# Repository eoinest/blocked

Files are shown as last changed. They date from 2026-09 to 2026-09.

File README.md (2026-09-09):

# blocked

A physical button for a very specific code review style.

Open a pull request in Google Chrome. Press the key. GitHub gets a
**Request changes** review that says:

> blocked

An ESP32-S2 Mini, one mechanical switch, a printed case, and a small native Mac
menu bar app. No browser extension, cloud service, or GitHub token on the board.

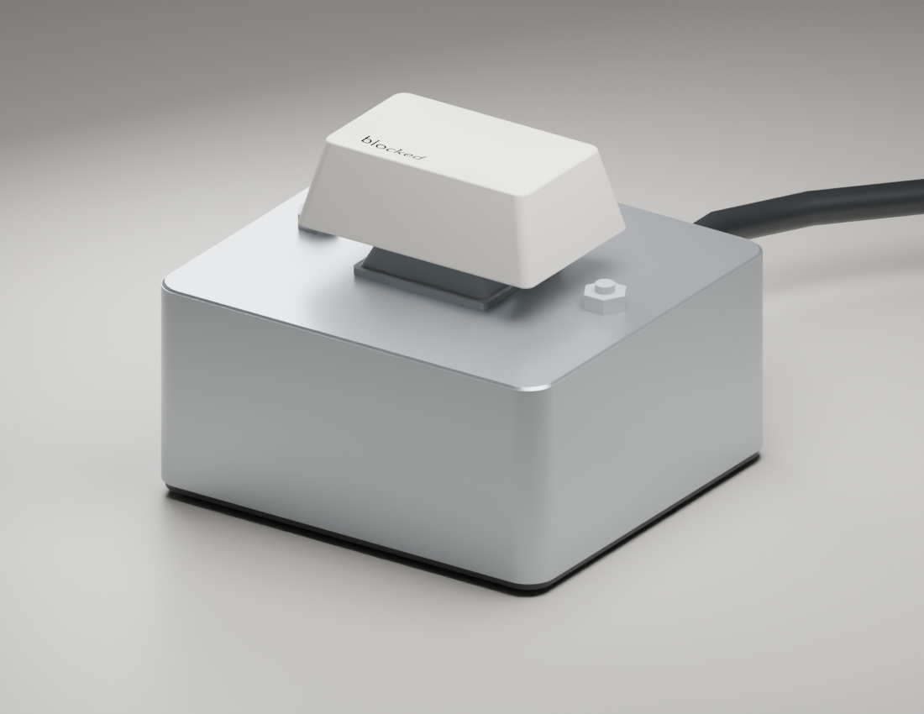
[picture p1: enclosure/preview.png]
Blender enclosure concept: blocked key


**Status:** initial prototype. Source, firmware, and printable enclosure files
are provided; physical assembly and an actual button-to-review test are still
required. The companion now has first-run setup, bundled GitHub support,
remembered enable/pause state and optional launch at login. A signed/notarized
release and clean-Mac acceptance testing are still outstanding.

Verified locally: ESP32-S2 firmware compile, button-state regression checks,
43 offline companion tests, a universal Intel/Apple Silicon Mac app build, and mesh
checks for the printable parts. [CI configuration](ci/) is supplied as
an inactive template because the initial publishing credentials lacked workflow
permission.

## The build

| Part | Plan |
| --- | --- |
| Controller | Your existing LOLIN-style ESP32-S2 Mini, powered by USB-C |
| Key | Gateron Baby Kangaroo 2.0 tactile switch with a custom 1.5u `blocked` keycap |
| Wiring | Two soldered wires: GPIO4 → switch → GND; internal pull-up |
| Case | 46 × 42 × 22 mm body; two M1.6 screws through dedicated PCB mounting holes; two M2 case screws; all screws enter from below with exposed nuts above; four PCB supports, rear USB-C cutout, recessed feet |
| Mac | Native Swift menu bar app, USB serial, Chrome Automation, existing `gh` credentials |

The board sends a debounced press over USB serial. The Mac app checks that
Google Chrome is frontmost, reads the active tab in its front window, validates
the GitHub PR URL, and runs:

```sh
gh pr review https://github.com/OWNER/REPO/pull/NUMBER --request-changes --body blocked
```

That command really posts a review. Use **Test next press (no review)** for diagnosis.
The review is authored by the account authenticated in **GitHub CLI**, which may
differ from the account signed into Chrome. GitHub's permissions and branch
rules still apply.

## General-purpose command buttons

[Key Command](key-command/README.md) is a separate macOS app for assigning each button a shell command or keyboard shortcut. It uses [separate firmware](firmware/key_command/README.md), supports multiple boards, and runs alongside Blocked. The [three-button print plate](docs/three-button-print.md) includes three enclosures and three blank Tab caps.

## Make one

For soldering and switch checks, open the [standalone USB Button Tester](docs/button-test.md).

For an immediately printable keycap, use the [three Tab shapes and combined
A1 print plate](keycap/printed/README.md), including socket-fit testers.

1. Start with the [condensed shopping list](BOM.md) and [custom keycap order settings](keycap/README.md), then check your board against [the hardware guide](docs/hardware.md).
2. Verify the switch coupon and clip the switch into the lid using the [key mounting guide](docs/key-mounting.md). Solder the two wires, then [build and flash the firmware](firmware/README.md).
3. [Build and install the Mac companion](companion/README.md). Its setup window
   reuses an existing GitHub sign-in or connects through the browser, then requests
   Chrome access. The default app includes its own GitHub helper.
4. Keep the button paused, choose **Test next press (no review)**, then focus a PR
   and press the key. Verify the target and body.
5. Check [component dimensions and remaining measurements](docs/component-accuracy.md), then print the fastener coupons and remaining [enclosure parts](docs/enclosure.md).
   Mount the PCB through its two dedicated holes with M1.6 × 6 mm screws, then
   close the lid with two M2 × 20 mm socket-cap screws. All screws enter from
   below with exposed nuts above; four pads support the board. Check your
   Maierke kit for these new screw lengths.
   Add the keycap and adhesive feet.
6. Enable Blocked once when ready. Its enabled/paused state survives restarts.

The [key mounting guide](docs/key-mounting.md) covers the switch's plate clips,
reinforced lid, centred Tab keycap socket, full travel and service access.

See [the staged bring-up checklist](docs/bring-up.md) for assembly and the
physical acceptance checks. Building the gift needs a USB data cable, a soldering iron,
and a Mac development toolchain. The recipient gets a pre-flashed button and
should only need the installed companion app; see the [experience target](docs/user-experience.md). The board uses no Wi-Fi.

## Customize it

The companion supports request-changes, comment, and approve review actions,
with an editable message. Its default is request-changes + `blocked`. The
enclosure is parametric so you can adjust dimensions and printer tolerances.
The initial supported browser is stable Google Chrome on macOS; the supported
GitHub host is `github.com`.

| Directory | Contents |
| --- | --- |
| [`firmware/`](firmware/) | ESP32-S2 Arduino sketch, pinned build configuration, button-state tests |
| [`companion/`](companion/) | Swift menu bar app, settings, app packaging, automated tests |
| [`enclosure/`](enclosure/) | Editable CAD, printable parts, fit coupon, preview |
| [`docs/`](docs/) | Sourced hardware research, architecture, assembly and validation |

[Architecture and alternatives](docs/architecture.md) explains why USB serial
and macOS automation were chosen. [Contributions](CONTRIBUTING.md) are welcome.

## License

MIT, including the original firmware, companion, documentation, and enclosure
design files. See [LICENSE](LICENSE).

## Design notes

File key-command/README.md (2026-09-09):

# Key Command

A separate macOS app that turns each ESP32-S2 button into a **shell command or keyboard shortcut**. Assign different actions to different buttons; each assignment follows the board's stable chip ID when USB paths change. It has its own app bundle, preferences, firmware identity and source package. The existing Blocked app remains independent.

## Install and use

1. Open `dist/KeyCommand-0.1.0-beta.dmg`, drag **Key Command.app** to Applications, and launch it. This beta is ad-hoc signed, not Apple-notarized; the included Start Here file explains the first-open step.
2. Flash additional boards with [Key Command firmware](../firmware/key_command/README.md). The original Blocked firmware is a different product and is not automatically converted. Wire each normally-open switch between GPIO 4 and GND.
3. Plug in a board using a USB data cable. Give it a name, choose **Shell command** or **Keyboard shortcut**, configure the action and enable it. New boards start disabled.
4. For shortcuts, explicitly grant Key Command Accessibility access. Pressing the physical button sends the shortcut to the app currently in focus. Shell-only use does not require Accessibility.
5. Leave Key Command running in the menu bar. Enable **Open at login** for automatic startup. Normal USB reconnection needs no reset-button presses or repeated configuration.

The recipient needs the app and a pre-flashed button. No GitHub login, Chrome extension, Homebrew or Swift installation is needed to run the app. Commands can of course depend on tools the recipient has chosen to install.

## Shell commands

Commands run with your macOS user's permissions through `/bin/zsh -lc`. Enter a command or script and choose its working directory. Use absolute executable paths when a tool is not on the configured PATH. Shell expansions, pipes and redirections work because this is an intentional command runner.

A harmless first check:

```sh
/usr/bin/say 'Button connected'
```

The app shows completion status and bounded output, provides a timeout and cancellation, and drops repeated presses while that button's action is running. Commands read from `/dev/null` rather than an interactive terminal. Commands requiring a password prompt or a full interactive terminal need a different workflow. Only configure commands you intend to execute; commands and output are local user data, never bundled into the DMG.

## Keyboard shortcuts

Record the shortcut in the app. A physical press sends a balanced key-down/key-up pair with the chosen modifiers to the focused application. The manual shortcut test provides time to switch to the target app. macOS Accessibility approval is requested only when you choose to grant it; the app does not change system permissions itself.

Keyboard layouts, secure text fields and reserved system shortcuts can affect whether a target accepts a synthesized shortcut. Confirm the actual target app's behavior. This mode does not type a shell command into a terminal.

## Connection behavior

- Only USB devices named **Key Command**, using the Espressif development-board VID, are candidates.
- A separate versioned handshake identifies each board by 12 uppercase hexadecimal characters.
- Multiple connected boards have independent assignments and connection state.
- Duplicate, malformed, unhandshaken and buffered burst events do not run actions.
- Reconnection and a pause after sleep start a fresh handshake; held buttons must be released before another action can fire.
- USB identity associates settings with hardware; it is not cryptographic authentication.

## Build and package

Requires macOS 13+ and the Xcode command-line tools. There are no external Swift package dependencies.

```sh
cd key-command
swift test
./scripts/build-app.sh
./scripts/package-release.sh
```

The scripts create a universal **arm64 + x86_64** app and a verified DMG with an Applications shortcut. They do not modify `/Applications` or flash boards. Artifacts are in `key-command/dist/` and excluded from Git.

For a Developer ID signed and notarized release, with your existing signing identity and Keychain notary profile:

```sh
./scripts/package-release.sh \
  --sign 'Developer ID Application: Your Name (TEAMID)' \
  --notarize-profile YOUR_EXISTING_PROFILE
```

No notarization upload occurs unless that option is supplied. Ad-hoc beta signing does not provide Apple notarization or stable Developer ID permission continuity across builds.

## Hardware and printing

The [three-button print plate](../docs/three-button-print.md) contains three copies of the latest enclosure and three blank Tab caps. The socket-hugging USB collar is still conditional on the actual board and seated cable; follow the [USB fit procedure](../docs/usb-fit.md) before committing to the complete print.

The [firmware guide](../firmware/key_command/README.md) covers build, explicit-port upload and protocol diagnostics. Firmware compilation and simulated transport tests do not replace physical tests with the additional boards.

## Platform references

Apple documents [Accessibility trust](https://developer.apple.com/documentation/applicationservices/1459186-axisprocesstrustedwithoptions) and [main-app login registration](https://developer.apple.com/documentation/servicemanagement/smappservice/mainapp). These system controls are separate from per-button action settings.

MIT licensed; see [LICENSE](../LICENSE).

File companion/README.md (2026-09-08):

# Blocked for macOS

For soldering checks, use the separate [USB Button Tester](../docs/button-test.md):
a live pressed/released display and counter with no GitHub actions.

A small native menu bar app connects the USB button to the pull request in the active Google Chrome window. No browser extension or injected JavaScript is needed. The default review is **Request changes**, with the body **blocked**.

## Recipient experience

The gift should arrive **assembled, flashed and tested**. The recipient installs
Blocked from the disk image by dragging it into Applications, opens it once,
and completes its setup window:

1. **GitHub:** the app checks for an existing GitHub CLI sign-in and displays the
   account. If needed, **Connect GitHub** displays a one-time code and opens
   GitHub's browser authorization page. No Terminal, token copying, or Homebrew
   installation is required by the default app build. GitHub calls this the
   **GitHub CLI** authorization because the bundled helper owns the sign-in.
2. **Chrome:** choose **Allow Chrome** and accept macOS's Automation prompt.
   Blocked reads the focused tab URL, not page contents. If permission was
   previously denied, the setup window explains where to change it in Settings.
3. **Enable Blocked:** the window shows the selected action and message. Leave
   **Open Blocked when I log in** checked to keep it available after restarting
   the Mac. macOS may require approval in Login Items.
4. Plug in the pre-flashed button with a USB data cable, open a PR in Chrome,
   and press. No serial-port selection or per-launch arming is needed.

Unplugging and reconnecting starts a fresh USB session automatically. The app
rescans for the button while disconnected, so a changed USB port name is fine.
Leave Blocked running in the menu bar; installing it alone does not start a
process after you explicitly quit it. With **Open at login** enabled, it starts
again when you sign into your Mac. No BOOT or RESET press is needed for normal use.

For the single file to send to a friend, see [packaging and distribution](../docs/distribution.md).

Enabled/paused state survives app restarts. **Pause button** stops submissions
until enabled again. Changing action/message or advanced settings requires
accepting the new configuration once. GitHub sign-in and Chrome's permissions
remain controlled by GitHub and macOS; the app cannot skip those consent screens.
The GitHub account used can differ from the one signed into Chrome.

Success and error feedback appears briefly without activating Blocked or stealing
Chrome's focus. **Last result…** retains the full message. For diagnosis, choose
**Test next press (no review)**: that one physical press detects the PR and shows
its action without launching a review command. For repeated bench tests, keep
Blocked paused and select this option before each test press.

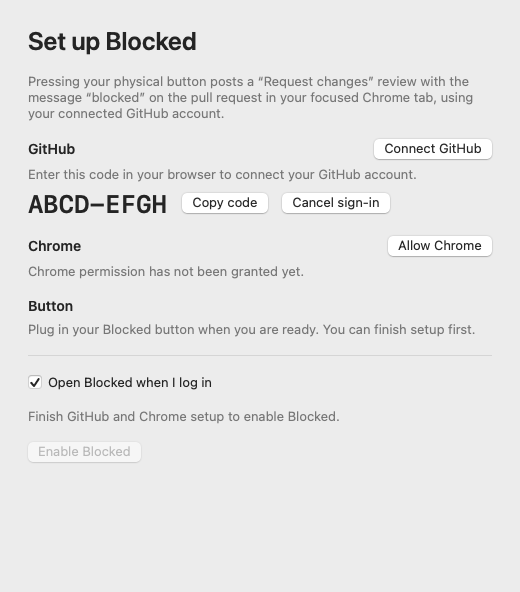
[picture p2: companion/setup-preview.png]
Native setup example with a fictitious device code


## Build and install

Development requires macOS 13+, Xcode/Swift 5.9+ and its selected command line
tools. The recipient does not need Xcode. There are no third-party Swift
packages. The default packaging script includes a pinned GitHub CLI executable
for Intel and Apple Silicon; archive SHA256 checks run before extraction and
on cached builds. Its MIT license ships with the app.

```sh
cd companion
swift test
./scripts/build-app.sh
```

Copy `dist/Blocked.app` to `/Applications`, then open it. The first packaging build
needs internet to download the verified helper archives. Later builds can use
`./scripts/build-app.sh --offline`. `--without-gh` is an explicit developer-only
option that uses an existing GitHub CLI installation; do not distribute that
variant as a self-contained app. See [bundled helper provenance](ThirdPartyNotices/GitHubCLI.md).

The helper reuses GitHub CLI's configuration and credential storage. Existing
Homebrew installations remain a fallback for developer builds. An absolute
helper path and serial port override remain available under Settings for
troubleshooting; neither is part of normal setup. Authentication output is
parsed in memory; device codes are not persisted. Cancel stops the sign-in
process, then rechecks whether credentials were saved before cancellation.

The script signs locally with an ad-hoc signature and stable bundle ID
`io.github.eoinest.blocked`. This is a **source-built prototype, not a notarized
installer**. A frictionless downloadable release still needs Developer ID
signing (`SIGNING_IDENTITY`), notarization and stapling, plus clean-Mac testing.
A rebuilt ad-hoc app may need Automation permission again. No login item is
registered by the build script: only enabling the setup checkbox or choosing
**Open at login** in the running app requests registration.

Chrome must be frontmost when the press is handled. Opening Blocked settings
means Chrome is no longer the target. Conversation, files (`/files` and `/changes`), commits and checks
views are supported; query strings and anchors are ignored when constructing
its canonical PR URL. Other browsers, Enterprise hosts, issues and arbitrary
subpaths remain unsupported. Chrome's “Allow JavaScript from Apple Events”,
Accessibility and Input Monitoring permissions are not required.

## What happens on a press

`USB CDC → identity + sequence check → foreground Chrome + active tab → strict PR URL parser → gh pr review`

The app uses `NSWorkspace.frontmostApplication` and read-only Apple events addressed to that exact process ID to read Chrome's front-window ID, active-tab ID, and URL. Addressing Chrome by bundle ID can select a separate background automation instance, so the reader never falls back to that lookup. It reads twice, requires matching results, and rejects reads taking one second or more. It then launches `gh` with a separate argument array, without a shell. The operation targets the captured PR URL. A tab switch after `gh` starts cannot recall the already-started network request.

There is no press queue. Busy presses, bursts, duplicate sequence numbers, data delayed by a blocked run loop/sleep, and presses inside the two-second debounce window are discarded. A live attempt reserves that PR for ten seconds, including failures. `gh` has a twenty-second timeout and is never retried automatically: a timeout may mean GitHub received the review but its response was lost. Check the PR before trying again. GitHub may reject self-reviews, closed PRs, or reviews the signed-in account cannot submit; those errors are shown as returned by gh.

No PR URL or review body is persisted by Blocked, except the configured message in macOS preferences. The latest result stays in memory. Subprocess output uses a private temporary directory removed on completion. User-supplied custom `gh` paths must point to an executable you trust.

## USB protocol v1

CDC serial, 115200 baud, 8 data bits, no parity, one stop bit, no hardware flow control. The host asserts **both DTR and RTS** because the ESP32 Arduino CDC connection implementation requires both. The firmware's USB product name is `Blocked Key`, using Espressif's vendor ID `0x303a` and the LOLIN S2 Mini's existing product ID `0x80c2`. Automatic discovery filters by vendor and product name; an explicitly configured `/dev/cu.*` port bypasses discovery only.

```text
host → board: HELLO\n
board → host: BLOCKED_KEY 1\n
board → host: PRESS 1\n
board → host: PRESS 2\n
host → board: RESULT DRY_RUN\n
host → board: RESULT OK\n
host → board: RESULT ERROR\n
```

Identity is a version/compatibility check, not cryptographic authentication. Sequence numbers must increase within a connection. A new connection starts a fresh session and flushes input. The host retries HELLO while awaiting identity; repeated identity responses do not reset the host's sequence check. The board requires a debounced release after handshaking before emitting a new press; holding the key while plugging it in cannot submit a review. Result lines are optional feedback and can be ignored by the board.

## Verification

`swift test` runs the offline regression suite and skips the opt-in Chrome integration test.
Coverage includes URL boundaries, exact window/tab identities, application or tab
changes during capture, slow reads, dry run without even looking up gh, busy
presses, per-PR failure cooldowns, and the production press coordinator through a
real local fake-gh subprocess. Runner tests check exact `--request-changes` and
`blocked` arguments, authentication/self-review/permission errors, silent failures,
interruptions, noninteractive execution, timeouts and no automatic retries.
These default tests make no network calls and never submit reviews. Additional
tests cover remembered enable/pause state, setup readiness, browser device-code
parsing, existing-account checks, cancellation, timeout, and stale auth callbacks.

For a real Chrome smoke test, close any sensitive modal dialogs and leave the
desktop idle, then run from `companion`:

```sh
BLOCKED_CHROME_INTEGRATION=1 swift test --filter ChromeIntegrationTests
```

This opens two disposable Chrome windows, switches a tab, checks PR versus issue
URLs, verifies rejection when Finder is foreground, and closes its own windows.
It restores the previously active app. macOS can request Automation permission for
the test runner. The fixture URLs need not resolve to real PRs; this tests URL
detection, not remote PR existence. It never invokes gh or submits a review.
If macOS prevents foreground activation, `BLOCKED_CHROME_INTEGRATION=reader`
tests real Apple-event window/tab responses with an injected foreground identity;
that mode **does not verify actual foreground-app detection**.

The Swift app and packaging can be built without hardware. A fresh recipient Mac
still needs its own first-run and physical unplug/replug checks. A test runner's
Automation permission does not establish that the packaged app has permission.
See the root bring-up instructions.

### Local verification — September 7, 2026

- Physical switch → ESP32 USB → packaged companion → focused Chrome PR → GitHub
  request-changes review with body `blocked` passed on the assembled device.
  The user confirmed success and dismissed the test review afterward.
- Fixed targeting when background Chrome automation processes share the same
  bundle ID as the visible browser; all reads now address the captured PID.
- Changed the per-PR cooldown to ten seconds and verified its boundary tests.
- The development app uses the user's existing GitHub sign-in; distributed
  artifacts contain the app and bundled CLI, not credentials or preferences.

### Local verification — September 5, 2026

- **Passed:** 43 offline tests, including the production press flow through fake gh.
- **Passed:** universal release build, Apple Silicon/Intel architecture check,
  and strict code-signature verification.
- **Unresolved:** the live Chrome smoke test could not establish its disposable
  window as the front window. Full-focus mode also encountered another foreground
  app. Reader-only mode still observed a different Chrome window after attempting
  to raise the fixture, so neither live mode is recorded as passing. The test
  cleaned up its fixture windows. Rerun interactively on an idle desktop.
- **Not performed:** any real GitHub review submission, packaged-app permission
  onboarding, or physical USB-button test.

Testing also fixed empty error messages from silent gh failures, added an explicit
ambiguous-result message for interrupted gh processes, and corrected the `lipo`
argument order in the optional CI template. That template remains inactive until
installed under `.github/workflows` with appropriate GitHub permissions.

## Primary references

- [Apple: frontmostApplication](https://developer.apple.com/documentation/appkit/nsworkspace/frontmostapplication)
- [Chromium: AppleScript support](https://www.chromium.org/developers/design-documents/applescript/) — installed Chrome's `Contents/Resources/scripting.sdef` additionally declares `active tab`, `URL`, and window/tab IDs.
- [Apple: NSAppleEventsUsageDescription](https://developer.apple.com/documentation/bundleresources/information-property-list/nsappleeventsusagedescription)
- [Apple: Apple Events entitlement](https://developer.apple.com/documentation/bundleresources/entitlements/com.apple.security.automation.apple-events)
- [GitHub CLI: gh pr review](https://cli.github.com/manual/gh_pr_review)
- [ESP32 Arduino: LOLIN board definitions](https://github.com/espressif/arduino-esp32/blob/3.3.1/boards.txt) and [USB CDC implementation](https://github.com/espressif/arduino-esp32/blob/3.3.1/cores/esp32/USBCDC.cpp)

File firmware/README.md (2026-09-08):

# ESP32-S2 firmware

The sketch turns one normally-open mechanical switch into a USB CDC serial device. It does not type keys, join Wi-Fi, or store GitHub credentials. The Mac app decides what a press does.

## Build

Install [Arduino CLI](https://arduino.github.io/arduino-cli/latest/installation/). Development uses CLI **1.3.1** and Arduino ESP32 **3.3.1**. The checked-in `sketch.yaml` pins the board core and USB settings; the first profile build downloads its dependencies.

From the repository root:

```sh
ARDUINO_NETWORK_CONNECTION_TIMEOUT=600s arduino-cli compile --profile s2-mini firmware/blocked_key
```

The first build downloads large tool archives for the ESP32 core; the longer network timeout avoids Arduino CLI's default 60-second download limit. [Arduino CLI configuration](https://arduino.github.io/arduino-cli/1.3/configuration/)

The profile uses `esp32:esp32:lolin_s2_mini`, **USB CDC On Boot = Disabled**, **USB MSC On Boot = Disabled**, and **USB DFU On Boot = Disabled**. CDC is disabled *on boot* because the sketch creates its own `USBCDC` interface with product name **Blocked Key** before calling `USB.begin()`; the running firmware still exposes USB serial. Do not enable the boot CDC instance as well.

For an entirely project-local tool cache (optional):

```sh
export ARDUINO_DIRECTORIES_DATA="$PWD/.arduino/data"
export ARDUINO_DIRECTORIES_DOWNLOADS="$PWD/.arduino/downloads"
export ARDUINO_DIRECTORIES_USER="$PWD/.arduino/user"
export ARDUINO_BUILD_CACHE_PATH="$PWD/.arduino/build-cache"
ARDUINO_NETWORK_CONNECTION_TIMEOUT=600s arduino-cli compile --profile s2-mini firmware/blocked_key
```

## Flash

Close the companion app, Button Tester and serial monitors first. Use a **data-capable** USB-C cable. Flashing replaces any existing MicroPython or other program on this board.

1. Hold the board's **0 / BOOT** button.
2. Tap and release **RST / RESET**, then release **0 / BOOT**. This selects the ROM USB downloader. Alternatively hold BOOT while plugging in USB, then release it.
3. Run `arduino-cli board list` and copy this board's `/dev/cu.usbmodem...` path.
4. Upload, replacing the example port:

```sh
arduino-cli upload --profile s2-mini --port /dev/cu.usbmodemYOUR_BOARD firmware/blocked_key
```

5. Tap RESET. The running device can have a different port path; the companion app discovers it again by USB product name.

The firmware disables serial-line reboot shortcuts, so use the physical BOOT + RESET sequence for subsequent uploads too. Both controls must remain serviceable after assembly: the first enclosure uses a removable lid retained by two underside screws, with wire slack for opening. Follow the [RESET / BOOT service procedure](../docs/enclosure.md#reset--boot-service-access); prove access with the actual board before final assembly. If the board never appears, first try another known data cable and inspect the board's actual model and pinout. The original ESP32 lacks the ESP32-S2's native USB controller; a USB-C connector alone does not imply compatibility.

## Protocol version 1

ASCII lines ending in LF. Input also accepts CRLF. USB CDC uses nominal 115200 baud, 8 data bits, no parity, one stop bit; the host must assert **both DTR and RTS** for the pinned Espressif implementation's connected state. The board advertises the LOLIN/Espressif development-board USB identity plus product name `Blocked Key`.

| Direction | Line | Meaning |
| --- | --- | --- |
| Host → board | `HELLO` | Start or restart an application session. |
| Board → host | `BLOCKED_KEY 1` | Device identity and protocol version. |
| Board → host | `PRESS 1` | Fresh press; counter increments each event until reboot (32-bit unsigned wrap). |
| Host → board | `TEST` | Start or restart button diagnostics; suppress action events. |
| Board → host | `BLOCKED_TEST 1` | Diagnostic protocol identity, followed immediately by a state snapshot. |
| Board → host | `STATE UP`, `STATE DOWN` | Released / pressed state during diagnostics. |
| Host → board | `RESULT OK`, `RESULT DRY_RUN`, `RESULT ERROR` | Optional feedback, currently ignored by this firmware. |

After every handshake, the switch must remain released for **25 ms**, then pressed for **25 ms**, before an event can fire. Booting with the key held, holding it down, contact bounce, and reconnecting while held do not create presses. Events before a handshake or while disconnected are discarded. Unknown and oversized input lines are ignored. Sequence numbers are for session deduplication, not durable event delivery. The device does not retry actions.

`BLOCKED_KEY 1` identifies compatible firmware; it is not cryptographic authentication. The USB connection has the privileges of the locally configured companion app.

## Test the switch and solder joints

Close the companion app before opening a serial monitor or button tester: only one program should own the board's serial port. Connect with DTR and RTS asserted, then send `TEST` followed by a newline. The board replies, for example:

```text
BLOCKED_TEST 1
STATE UP
```

The initial snapshot samples the pin immediately, so a button held when testing starts reports `STATE DOWN`. Later changes must remain stable for **25 ms** before being reported. The board also repeats its current debounced state **1,000 ms** after the latest state report; a held button therefore remains visibly testable. Short contact bounce creates no extra transitions. Diagnostics never emits `PRESS` or advances its sequence counter.

Press and release several times: expect `DOWN` when held and `UP` when released. An always-UP reading can indicate an open connection; an always-DOWN reading can indicate a short or use of the wrong switch contacts. For the selected normally-open switch, the two wires connect GPIO **4** to **GND**; the firmware supplies the pull-up internally.

Send `HELLO` to return to production mode. It replies `BLOCKED_KEY 1` and requires a fresh stable release before the next press can trigger an action. Sending `TEST` again restarts diagnostics with another snapshot. Disconnecting or resetting ends either session; reconnect and send a new command. A serial monitor can be used for this test without GitHub credentials or an open browser.

## Verification

The ESP32-S2 sketch, including diagnostic mode, compiled locally with the pinned profile and Arduino CLI 1.3.1: **302,118 bytes flash** (23%) and **34,736 bytes global RAM** (10%). The installer reported a network failure fetching the unrelated RISC-V toolchain; the cached Xtensa/S2 toolchain completed the build successfully. The portable production and diagnostic state checks also passed. This is a compile and logic check, not a physical-device test; no board was flashed during verification.

Run the portable button-state regression checks:

```sh
c++ -std=c++17 -Wall -Wextra -Werror firmware/tests/button_gate_test.cpp -o /tmp/blocked-key-button-test
/tmp/blocked-key-button-test
```

The checks exercise contact bounce, no repeat while held, held boot, reconnect, short release, and unsigned clock wrap. Diagnostic checks cover immediate held/released snapshots, debounced transitions in both directions, heartbeat timing, mode changes, disconnect reset, and heartbeat clock wrap. They do not emulate USB hardware. Physical USB enumeration, electrical wiring, cable behavior, and actual switch feel still need a bench test on your board. Start with `TEST` for wiring, then the companion app's dry-run mode; use the assembly checklist in [hardware.md](../docs/hardware.md).

References: [Espressif USB CDC API](https://docs.espressif.com/projects/arduino-esp32/en/latest/api/usb_cdc.html), [Espressif USB flashing guide](https://docs.espressif.com/projects/arduino-esp32/en/latest/tutorials/cdc_dfu_flash.html), [pinned board definitions](https://github.com/espressif/arduino-esp32/blob/3.3.1/boards.txt), [LOLIN Arduino instructions](https://docs.wemos.cc/en/latest/tutorials/s2/get_started_with_arduino_s2.html).

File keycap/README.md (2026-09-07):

# Order the `blocked` keycap

Want a printable cap while the custom one is being made? See the
[three Blender-designed Tab prototypes and A1 print plate](printed/README.md).

Recommended: [Max Keyboard — Custom Art & Custom Color Keycaps](https://maxkeyboard.com/custom-art-icon-or-text-cherry-mx-keycaps.html).
Use a **standard Tab-sized, 1.5u keycap**, with the custom legend **`blocked`**.
The exact 1.5u configuration was checked in the live selector on September 5,
2026 at **US$11**, quantity one, before shipping and tax.

| Field | Choose |
| --- | --- |
| Keycap Size | **R3 1x1.5 (Tab / \|)** |
| Keycap Color | **White** (Beige is available if you prefer a warmer cap) |
| Print Area | **TOP Print only** |
| Quantity | **1** |
| Upload Your Artwork | [blocked-tab-upload.svg](blocked-tab-upload.svg) (preferred vector) or [blocked-tab-upload.png](blocked-tab-upload.png) |

The current design uses **Apple SF Compact Regular**, rendered from the font
already installed on the Mac. The lowercase word sits at the **lower-left of
the TOP surface**, as viewed by the person typing. Use the selected **R3 1x1.5
(Tab / \|)** option, White, TOP Print only. The lettering is neutral gray
**sRGB #8B8B8B (RGB 139, 139, 139)**, chosen from Apple’s official product image after comparison with three independent photos.
See [color research and samples](color-research.md).
It is not an official Apple ink specification; ask the printer to confirm the
printed gray on the white cap in the proof.

Paste this into the comments field:

> Print the supplied lowercase “blocked” lettering in neutral gray (sRGB #8B8B8B) on the TOP surface
> of the white R3 1x1.5 Tab keycap. Preserve the supplied font shapes. Set the
> word approximately 9 mm wide, with its visible ink 2 mm from the usable top
> surface's LEFT and FRONT (lower) edges, viewed from the typist's position.
> Do not center the word or enlarge it to fill the key. The transparent canvas
> communicates placement; adjust to your actual printable surface. Please
> provide a placement proof before printing.

The SVG contains outlined lettering only, with no embedded font or live text.
The transparent PNG is 2700 × 1800 px, under 200 KB, satisfying the shown
300 px minimum and 2 MB maximum. Upload **one** of these two files. The
[placement preview](blocked-tab-placement-preview.png) is illustrative and
contains a white key shape; **do not upload the preview as print artwork**.
The 27 × 18 mm artwork canvas conveys layout intent, not verified dimensions
of the vendor's sculpted top surface. The older `blocked-artwork.png` is
superseded by these files.

[Apple identifies SF Compact](https://developer.apple.com/fonts/) as part of
its San Francisco family. This is an Apple-style composition, not a claim that
the exact weight, spacing and geometry match every Apple keyboard generation.
The artwork was rendered with the macOS-bundled font; no font file is included.
[macOS Sequoia's license, section 2E](https://www.apple.com/legal/sla/docs/macOSSequoia.pdf)
addresses display/printing with bundled fonts and separate font-embedding
restrictions. The standalone developer-font download has different terms;
noncommercial intent alone is not blanket font permission.

To regenerate on a Mac with the bundled SF Compact font, run
`swift keycap/make-artwork.swift` from the repository root. The script creates
the two upload files, the placement preview and [artwork-spec.json](artwork-spec.json).
No order or vendor proof has been requested by the project.

Max's [profile guide](https://maxkeyboard.com/mechanical-keycap-layout-and-size-chart.html)
describes OEM profile, and its [keycap guide](https://blog.maxkeyboard.com/dwkb/keycap-types/)
describes colored caps as ABS. This is an MX-compatible, non-shine-through cap.
“Cherry MX compatible” describes the mount, not Cherry profile. The standard
1.5u Tab option is the intended fit; exact external dimensions and stem location
were not verified against a manufacturer drawing. The Blender reference is
approximate, so check seating and free return before final assembly.
The [key mounting guide](../docs/key-mounting.md) explains the centred MX socket,
switch clips, full-travel checks and removal. The hollow socket shown in Blender
is illustrative; it does not replace the manufacturer's moulded cap.

For US delivery, the [shipping policy](https://maxkeyboard.com/shipping-information.html)
lists 3–5 business days for production plus 3–7 business days for standard
ground shipping. That is an estimate, not a guaranteed birthday arrival date;
the shipping charge appears at checkout.

If PBT is more important than a one-cap order,
[Gimsun's custom PBT cap](https://gimsuncustom.com/products/custom-pbt-ansi-layout-keycap-single-key?variant=49847600808247)
offers **Cherry Profile → R3 → 1.5u (Tab)** and dye-sublimation printing at
$3.99 each, but its product-specific minimum is **three caps** ($11.97 before
shipping/tax). Its customizer resets the size, so select it again after opening
the editor. Max remains the selected BOM item.

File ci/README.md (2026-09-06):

# Optional GitHub Actions checks

`checks.yml` defines companion tests and universal app packaging, portable
button-state tests, and a firmware compile with the pinned Arduino profile.

The credentials used for the initial publication lacked GitHub's `workflow`
scope. The workflow is included here as a template; **GitHub Actions is not
enabled by this file**.

To activate it, use an account/token allowed to write workflows and move
`ci/checks.yml` to `.github/workflows/checks.yml`, then commit and push. The same
checks can be run locally using the commands in the component READMEs.

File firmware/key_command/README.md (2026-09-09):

# Key Command firmware

This is a separate ESP32-S2 Mini firmware for the Key Command companion app. It
does not change or share source dependencies with `firmware/blocked_key`. Connect
a normally-open switch between **GPIO 4 and GND**; the internal pull-up supplies
the input bias. Actions are configured and executed on the Mac. The board never
receives shell commands, stores credentials, or connects to Wi-Fi.

## Build and explicitly select a board to flash

Use Arduino CLI **1.3.1**. `sketch.yaml` pins Arduino ESP32 **3.3.1**, LOLIN S2 Mini,
and USB CDC On Boot disabled; the sketch creates its own USB CDC interface.

From the repository root:

```sh
ARDUINO_NETWORK_CONNECTION_TIMEOUT=600s arduino-cli compile --profile s2-mini --build-path /tmp/key-command-build firmware/key_command
```

Compilation does not flash anything. To install it on an additional board, close
apps holding that board's serial port, hold **BOOT**, tap **RESET**, then release
BOOT. Run `arduino-cli board list` and identify that board's current port. The
following upload replaces that board's existing firmware; use its actual port:

```sh
arduino-cli upload --profile s2-mini --input-dir /tmp/key-command-build --port /dev/cu.usbmodemYOUR_NEW_BOARD firmware/key_command
```

Tap RESET afterward. Do not select the existing Blocked board unless you intend
to replace its firmware. There is no automatic port selection or upload step.

## Protocol version 1

ASCII lines use LF or CRLF. Open at nominal **115200, 8N1**, asserting **both DTR
and RTS**. USB product name is `Key Command`; VID/PID remain the board defaults
(Espressif VID `0x303A`). The USB serial string is the same 12-character uppercase
hex ID returned by the handshake, derived from the factory eFuse base MAC. It
remains stable across reset and firmware uploads on that chip. This identifier
is for associating settings with a board, not authentication.

| Direction | Line | Meaning |
| --- | --- | --- |
| Host → board | `KEY_COMMAND_HELLO` | Start/restart production session. |
| Board → host | `KEY_COMMAND 1 AABBCCDDEEFF` | Version and example device ID. |
| Board → host | `PRESS 1` | One new physical press; unsigned 32-bit counter. |
| Host → board | `KEY_COMMAND_TEST` | Start/restart diagnostics; suppress presses. |
| Board → host | `KEY_COMMAND_TEST 1 AABBCCDDEEFF` | Diagnostic identity; followed by a state snapshot. |
| Board → host | `STATE UP` or `STATE DOWN` | Diagnostic released/pressed state. |

Plain `HELLO` and `TEST` are ignored, so the Blocked app cannot activate this
firmware. Commands must match exactly. Unknown lines, non-ASCII/control bytes,
embedded CR, and lines longer than 63 characters are discarded through the next
LF. A single trailing CR is accepted. Parsing consumes at most 64 received bytes
per loop so continuous input cannot prevent button sampling.

Every production handshake requires a **25 ms stable release**, followed by a
**25 ms stable press**, before emitting an event. A held button never repeats.
Booting, reconnecting, or handshaking while held produces no action. Disconnection
clears mode and partial input; a new handshake is required. Offline presses are
discarded. The sequence increases only for production events, persists across
handshakes while powered, resets at reboot, and wraps modulo 2³². It is not a
delivery queue; hosts should deduplicate within a session and never replay old
events after reconnecting.

Diagnostics sends an immediate raw input snapshot, then debounced transitions
and a heartbeat 1,000 ms after the last state report. It never emits `PRESS` or
advances its counter. `KEY_COMMAND_HELLO` returns to production with a fresh
release-before-arm requirement. Serial reboot shortcuts are disabled; use the
physical BOOT/RESET controls to enter the downloader.

## Portable checks

```sh
c++ -std=c++17 -Wall -Wextra -Werror -fsanitize=address,undefined firmware/tests/key_command_test.cpp -o /tmp/key-command-test
/tmp/key-command-test
```

These exercise exact handshakes and cross-product isolation, oversized/binary
input and parser recovery, partial commands across disconnection, held boot,
contact bounce, no repeat, release-before-arm, offline suppression, diagnostics,
mode changes, heartbeats, and unsigned clock wrap. They do not emulate USB or
prove physical switch wiring. No board is flashed by the tests.

Verified locally with CLI 1.3.1 and the pinned ESP32 3.3.1 profile: **302,342 bytes
flash**, **34,752 bytes global RAM**. All portable checks passed with address and
undefined-behavior sanitizers, and the existing Blocked tests also passed. The
profile installer reported an unavailable unrelated RISC-V download; the cached
Xtensa/S2 tools completed compilation successfully. No board was flashed. Local
compiled images and their source hashes are in the ignored
`firmware/dist/key-command/` directory, with metadata in `build-info.json`.

The local distribution copy is
`key-command/dist/KeyCommand-ESP32-S2-0.1.0.bin`, with a `.bin.sha256` sidecar.
This is a **4 MiB merged image for ESP32-S2**, written at flash offset **0x0**
if using an external flashing tool. Its embedded bootloader at `0x1000`, partition
table at `0x8000`, and application at `0x10000` were compared byte-for-byte with
the actual build outputs. Do not upload this merged image at the application's
`0x10000` offset. The Arduino upload command above selects the separate images
and their offsets automatically.

Implementation references: [pinned Espressif USB API](https://github.com/espressif/arduino-esp32/blob/3.3.1/cores/esp32/USB.h),
[pinned USB implementation](https://github.com/espressif/arduino-esp32/blob/3.3.1/cores/esp32/USB.cpp),
and [pinned board definitions](https://github.com/espressif/arduino-esp32/blob/3.3.1/boards.txt).

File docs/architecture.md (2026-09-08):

# How one key becomes a review

```text
MX switch ── two wires ── ESP32-S2 mini
                              │
                         USB-C / CDC serial
                              │
                       Blocked menu bar app
                              │
                  Is Google Chrome frontmost?
                              │ yes
                  Read front window's active tab
                              │
                    Validate github.com PR URL
                              │
                  gh pr review URL --request-changes
                                   --body blocked
```

The board knows about presses. The Mac knows about the browser and GitHub.
There is no Wi-Fi setup, firmware token, hosted server, or browser extension.

## Why this architecture

| Approach | What it needs | Decision |
| --- | --- | --- |
| USB CDC + native Mac app | One app with bundled gh; Chrome permission; browser sign-in if needed | Implemented. A structured press event is easy to distinguish from keyboard input. |
| USB keyboard shortcut | Global hotkey capture or keyboard automation; a reserved shortcut | Possible later, but a shortcut can conflict with another app and cannot identify the target PR by itself. |
| Chrome extension + native messaging | Extension and installed native host | Useful for more browsers or richer page context; additional installation for this gift. |
| ESP32 calling GitHub over Wi-Fi | Wi-Fi provisioning and credentials on device; still needs the active URL from the Mac | Adds setup without removing the desktop integration. |

The ESP32-S2 supports native USB device operation. Its USB data lines are GPIO19
and GPIO20, so those are reserved for USB. See the
[Espressif USB device guide](https://docs.espressif.com/projects/esp-idf/en/stable/esp32s2/api-reference/peripherals/usb_device.html).

Chrome exposes its windows, active tab, and tab URL in its
[AppleScript dictionary](https://chromium.googlesource.com/chromium/src.git/+/lkgr/chrome/browser/ui/cocoa/applescript/scripting.sdef).
The app first checks macOS's frontmost application. It must not select a stale
Chrome window when the user is working in a different app. With multiple Chrome
windows, the target is the active tab in Chrome's front window.
Read-only Apple events address the captured foreground process ID directly;
bundle-ID lookup can select an unrelated background Chrome automation process.

macOS asks the user to let Blocked automate Chrome; the app includes an
[Apple Events usage description](https://developer.apple.com/documentation/bundleresources/information-property-list/nsappleeventsusagedescription).
Reading the URL does not require enabling Chrome's “Allow JavaScript from Apple
Events” setting. This integration does not read page content or passwords.

The companion passes the validated URL and review body as separate process
arguments to [GitHub CLI](https://cli.github.com/manual/gh_pr_review). It uses the
account already authenticated with GitHub CLI, or connects it through the app's
browser device-code flow. The Chrome website login can
be a different account: the review is always authored by the **CLI account**.
GitHub still enforces review permissions and repository rules. A request-changes
review's effect on merging depends on those rules; the button does not create
a branch protection rule.

## Behavior and limits

- Complete account/Chrome setup and enable once; remember enable/pause across
  restarts. Offer a one-press diagnostic that never submits a review.
- Require a fresh button press, the identified serial protocol, an eligible PR
  URL, and Google Chrome as the frontmost app.
- Never submit a review merely because the device is connected or a key is held
  during connection. Debounce mechanical bounce and reject repeated events.
- Ignore presses during an in-flight operation. Do not build a queue of reviews.
- Treat a failed or timed-out network request as uncertain; do not retry it
  automatically. Check GitHub before pressing again.
- The first version targets macOS, stable Google Chrome, and `github.com`.
  Enterprise hosts and other browsers need an explicit implementation.
- USB/Apple Events/network operations are not an atomic snapshot. A tab or PR
  can change during a request; the software reduces that window but cannot make
  an already submitted GitHub request disappear.

For settings, installation, and implementation details see
[the companion README](../companion/README.md). For the exact wire protocol see
[the firmware](../firmware/).

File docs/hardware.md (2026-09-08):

# Build the physical key

For the gift, my pick is one **Gateron Baby Kangaroo 2.0**, a **1.5u MX-compatible keycap** printed or engraved with `blocked`, and your S2 Mini. Gateron describes an early, strong tactile action with nominal 59 ± 8 gf operating force and a five-pin MX structure. That is a good direction for a deliberate, satisfying one-purpose press; the exact feel still needs a sample in your hand. [Gateron product page](https://www.gateron.com/products/gateron-baby-kangaroo-20-tactile-switch-set)

**CHERRY MX2A Brown** is the easy-to-source, gentler alternative. It has 2 mm pre-travel and 4 mm total travel; CHERRY lists 45 cN actuation and 55 cN at the tactile peak. It is a soft bump, so choose the Baby Kangaroo if the gift should feel more emphatic. The wider 1.5u cap still uses one centered switch; choose a cap with a single centered MX stem and check off-center presses. [CHERRY Brown specifications](https://www.cherry.de/fr-fr/produit/mx2a-brown)

Feel is personal. A single-switch sample or small tester is more useful than buying an entire keyboard's worth for this project. The printed enclosure changes the sound too. Use a manufactured cap for the nicest finger surface and durable stem; an FDM cap is fine for experimenting with the legend and shape. Choose standard MX switches with **metal electrical contacts**; optical, Hall-effect, and inductive variants require different electronics.

## Shopping list and keycap

Use the condensed [BOM](../BOM.md) for quantities and the chosen parts.
The selected cap is **Max Keyboard’s custom-printed OEM-profile 1.5u Tab cap**,
white with black `blocked` on top; [exact order settings and artwork](../keycap/README.md)
are included. The Blender cap remains an approximate visual reference, so check
full travel and off-center presses with the purchased cap.

[Switch alternatives](switch-research.md) are kept separately from the shopping
list. The build needs no battery, keyboard PCB, stabilizer, diode, or external
resistor.

For the mechanical connection, follow the [key mounting guide](key-mounting.md):
flange on top of the lid, both switch clips latched underneath, and the cap
pressed straight onto the centred MX stem. The lid ribs carry the key load;
wires and ESP32 pins do not support the switch.

## Wiring

Unplug USB before soldering. The only two connections are:

```text
          ESP32-S2 Mini                         MX switch

  3.3 V -- internal pull-up -- GPIO4 / pad 4 ---- metal contact A
                                                 /  normally open
                              GND ------------- metal contact B

  USB-C ==================== Mac (power + native USB data)
```

The two switch contacts have no polarity. Pressing the switch connects GPIO4 to ground, which the firmware reads as LOW. The released input reads HIGH through `INPUT_PULLUP`. **Do not wire the switch to 5 V, VBUS, or 3V3.** Do not use the board's BOOT button/GPIO0 for the gift key. GPIO19 and GPIO20 are USB D− and D+ and must remain reserved for USB. The reference firmware uses **GPIO4**, the pad marked `4` or `IO4`, not the fourth physical pad from an edge. [Official schematic](https://docs.wemos.cc/en/latest/_static/files/sch_s2_mini_v1.0.0.pdf)

A “3-pin” MX switch has two metal electrical terminals and one plastic locating post. A “5-pin” version adds two plastic stabilizing posts. Solder to the **metal terminals**, not the plastic posts or optional LED contacts. With the board unplugged, a multimeter across the switch terminals should show open circuit when released and continuity when pressed.

1. Verify the switch and cap on the printed plate coupon first, then clip the switch into the final lid. Leave the keycap off while soldering and support the lid without loading the stem.
2. Tin the wire ends and the two switch terminals, then solder one wire to each. Follow the switch manufacturer's soldering limits; avoid holding heat on the plastic body. Use the soldering kit's stand, ventilation and eye protection.
3. Solder the other wire ends to GPIO4 and GND on the board. Short stripped ends and small joints are easier to insulate in the enclosure. No headers are needed.
4. Cover bare joints with heat-shrink or insulating tape, inspect for solder bridges, and check that pressing the key closes only the intended GPIO-to-ground path.
5. Flash and test with the enclosure open, then route wires clear of the stem, plate clips, USB connector and screws. Leave a little lid service slack without allowing wire to sit on top of board components.

## Check your particular S2 Mini

The [reference board dimensions](https://docs.wemos.cc/en/latest/_static/files/dim_s2_mini_v1.0.0.pdf) and pin labels describe the WEMOS/LOLIN design. The [selected seller listing](https://www.aliexpress.us/item/3256812318584460.html) shows an S2 Mini V1.0.0 with two dedicated mounting holes near the antenna. The revised enclosure uses those holes with M1.6 screws; it does not cover or fasten through the 32 electrical header holes. Boards sold as “S2 Mini” can differ in PCB outline, USB socket position and component heights. Measure the actual board and inspect both sides before printing the finished shell. See the [mounting layout](enclosure.md) and [component accuracy record](component-accuracy.md). The included design assumes no tall soldered headers. A board with a USB-to-UART bridge rather than native S2 USB will not enumerate as this firmware expects.

The USB socket must have clearance for the **cable's molded plug**, not only the metal connector. Test that the cable seats fully before tightening the case. Keep access to the board's BOOT and RESET buttons during development. See [firmware build/flash instructions](../firmware/README.md).

## First bench test — still required

For a simple wiring check before testing reviews, use the standalone
[USB Button Tester](button-test.md) to see live press/release state and a counter.

This project has not yet been soldered or physically printed and fitted. Complete these checks before using the gift for real reviews:

- With Blocked paused and **Test next press (no review)** selected, connect the board while the key is held. There should be **no action**. Release it and make a fresh press.
- Check one event per press, no repeated event while held, and deliberate separate presses working normally.
- Unplug, hold the key, reconnect: again no action until release then press. Repeat after sleep/wake and restarting the companion.
- Before each further diagnostic press, select **Test next press (no review)** again; keep the button paused.
- Open a throwaway PR in the frontmost Chrome window and inspect the dry-run target. Then try another Chrome tab, another window, and a different foreground app; verify the selected target and guard behavior.
- Only after the preview is correct, enable live actions and press on a test PR that the authenticated user did **not** author. Verify one review with body exactly `blocked`.
- Finally fit the lid, confirm the key travels freely and the cable seats fully, then add the feet or removable desk pad.

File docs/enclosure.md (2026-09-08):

# Printable enclosure and mounting

The revised case is **46 × 42 × 22 mm** before the exposed nuts/keycap. It uses the same S2 Mini board, snap-in Gateron switch and 1.5u Tab cap. This revision responds to the assembled prototype: covered nuts were awkward to fit, and the two-point PCB support allowed flex.

**All four screws now enter from underneath. All four nuts are open from above.** The PCB has four support locations, all at **z = 5.5 mm**. The two antenna-end supports retain the existing mounting holes; the two USB-end supports are plain bearing pads with no holes or screws. The revised parts have nominal geometry checks; the new print has not yet been physically fitted.

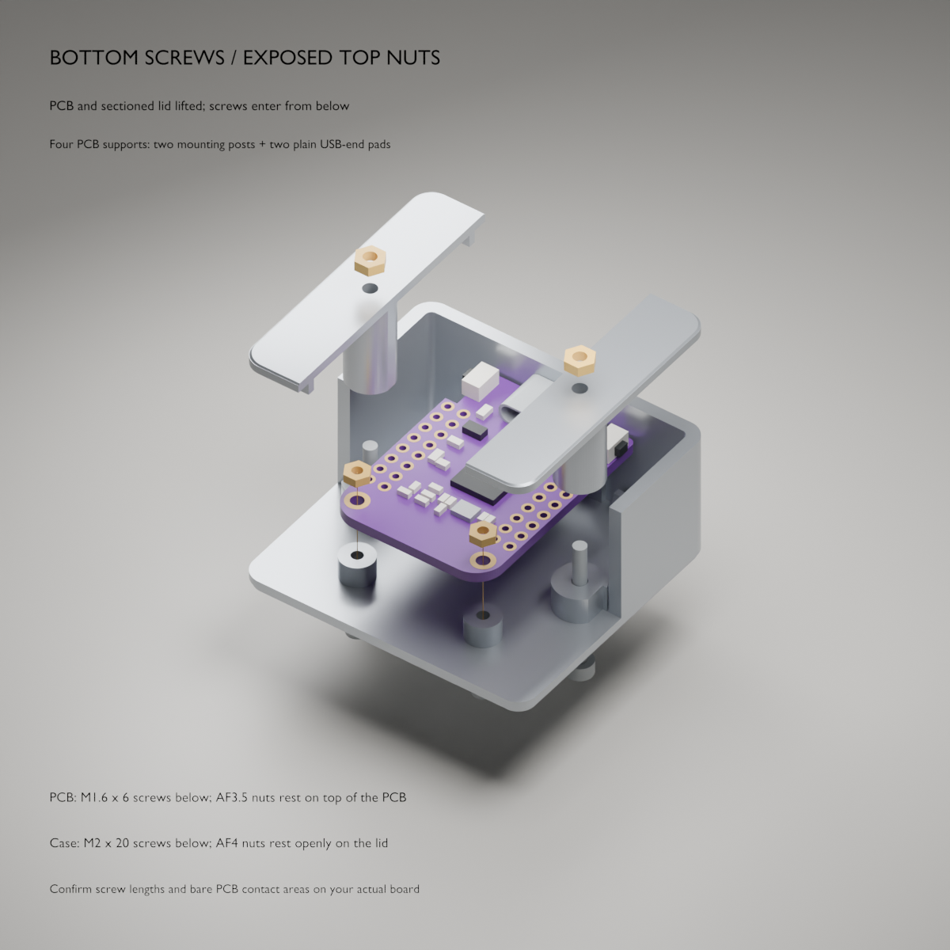
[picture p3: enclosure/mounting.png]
Revised mounting diagram


## Mounting and hardware

| Quantity | Part | Installation |
| --- | --- | --- |
| 2 | **M1.6 × 6 mm socket-cap screws**, 0.35 mm pitch | Up through the bottom of the base and the two existing Ø2 mm PCB holes |
| 2 | M1.6 hex nuts, modeled AF3.5 × 1.3 mm | Rest openly on top of the PCB; accessible with the lid off |
| 2 | **M2 × 20 mm socket-cap screws**, 0.4 mm pitch | Up through the bottom of the base and lid |
| 2 | M2 hex nuts, modeled AF4 × 1.6 mm | Rest openly on top of the lid |

Lengths exclude the heads. These are **different lengths from the previous M1.6 × 4 / M2 × 8 design**. Check the compartments in your [ordered Maierke kit](https://www.amazon.com/dp/B0GKFMJH24?th=1); inclusion of 6 mm M1.6 and 20 mm M2 screws has not been confirmed. Reuse its matching nuts. Both nominal screw heads use a 1.5 mm hex key.

There are **no captive pockets, roofs over nuts, or side-loading slots**. Hold an exposed nut with fine pliers while turning its screw from below. Remove the press-fit keycap for easier access to the two case nuts. The modeled nut-to-cap gap is enough for the parts themselves, not a guarantee that a socket wrench fits between them. No washers, inserts or adhesive are required by this nominal stack.

The switch still snaps into the 1.5 mm plate and the keycap presses onto its MX stem. See [key mounting](key-mounting.md).

## Board supports and clearances

Coordinates use the case bottom as z = 0 and USB toward +y.

| Feature | Revised dimensions / location |
| --- | --- |
| PCB outline | 25.4 × 34.3 mm, centered at y = 1.5 mm |
| PCB underside / top | z = 5.5 / 7.1 mm, assuming 1.6 mm PCB thickness |
| Antenna-end mounting supports | x = ±10.2, y = −12.35 mm; use the two original Ø2 mm holes |
| USB-end left contact | 2 × 1 mm at x = −9.5, y = 17.9 mm |
| USB-end right contact | 2 × 1 mm at x = 11.0, y = 17.9 mm |
| All four support tops | z = 5.5 mm |
| PCB bottom head recesses | Ø3.6 mm, 2.8 mm deep |
| Case bottom head recesses | Ø4.4 mm, 4.4 mm deep; local pad top z = 6.2 mm |
| Exposed PCB nuts | z = 7.1–8.4 mm; nominal screw tips z = 8.8 mm |
| Exposed case nuts | z = 22.0–23.6 mm; nominal screw tips z = 24.4 mm |
| Feet | Four 8 × 8 mm recesses at x = ±17, y = ±15 mm, moved clear of all screw entries |
| Switch / USB aperture | 14.1 mm square × 1.5 mm plate / 9.6 × 3.6 mm rounded socket collar |
| USB throat / lead-in | R1.65 collar; center z = 8.7 mm; 13.5 × 7.6 mm outer recess and 0.4 mm lead-in |

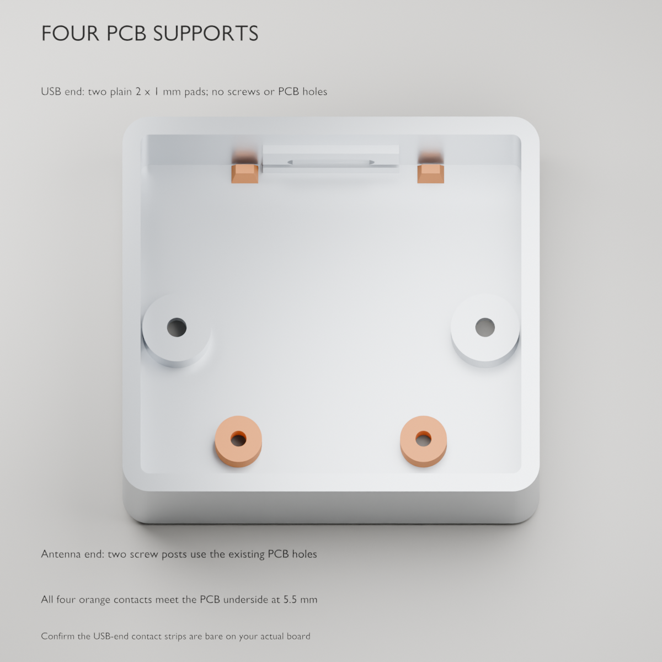
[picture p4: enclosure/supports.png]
Four PCB support locations


The small USB-end contact patches were chosen from the official board underside photo to avoid the button anchor/solder regions. They are near the two corners and supported from the base. **Check that these patches touch bare PCB on your actual clone**, not a solder joint or component. No electrical header holes are used for mounting. The source model preserves access around all 32 GPIO holes and the USB connector; solder and your wire routing are not fully modeled.

The board should rest evenly without rocking before nuts are fitted. All four contacts have the same nominal height; do not tighten the screws to force a bowed board onto a high printed support. See the [component accuracy record](component-accuracy.md) and [fastener stack audit](fastener-fit.md).

## USB fit

The **9.6 × 3.6 mm rounded collar** follows the modeled socket shell with 0.2 mm clearance per side. It sits inside a larger cable-access recess. A backside relief clears the PCB edge, retaining a 0.5 mm lower lip. The exact socket dimensions remain unmeasured.

**This revision requires a physical seating test:** the fully seated cable shoulder must clear the collar face, nominally requiring at least 0.35 mm ahead of the socket lip. Print the registered PCB cradle first. The model checks this conditional clearance but cannot establish it for your actual cable. See [USB dimensions, sources and fit procedure](usb-fit.md).

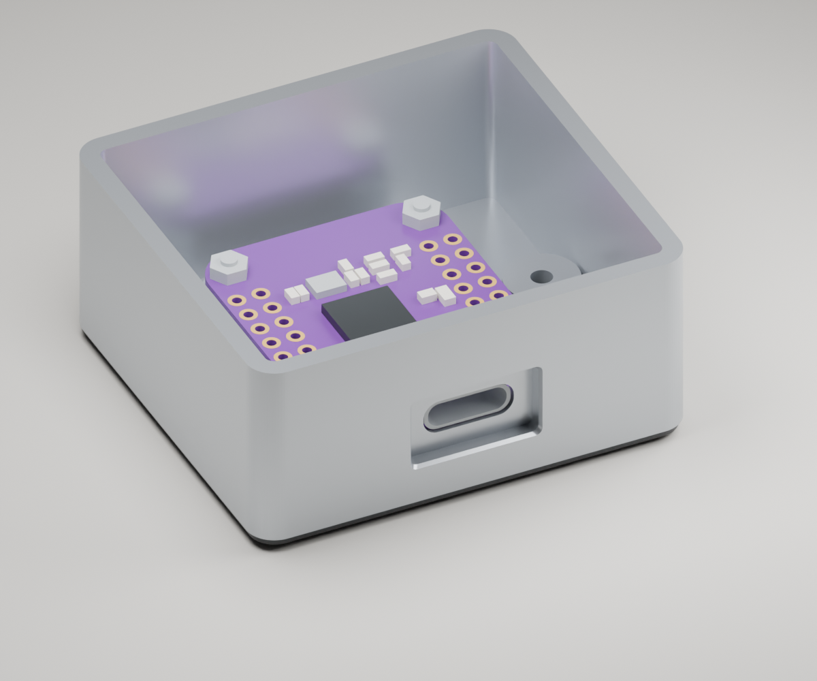
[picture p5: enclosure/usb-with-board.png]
USB opening with ESP32

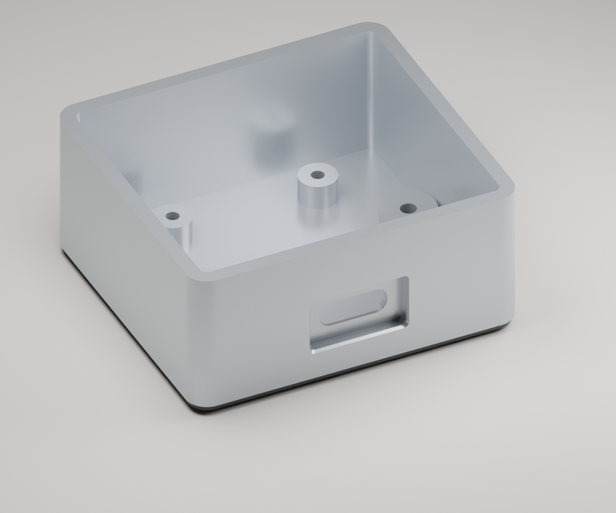
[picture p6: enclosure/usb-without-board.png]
USB opening without ESP32


## Files and Blender workflow

- [blocked-print-plate.stl](../enclosure/stl/blocked-print-plate.stl): **revised base and lid in one print file**, floor/top-down respectively, 6 mm apart.
- [blocked-print-plate-with-coupons.stl](../enclosure/stl/blocked-print-plate-with-coupons.stl): base, lid, switch, fastener and USB coupons together.
- [blocked.blend](../enclosure/blocked.blend): editable Blender assembly. PRINTABLE contains case parts and coupons; other collections are component references.
- [usb-review.blend](../enclosure/usb-review.blend): matched review scenes with the ESP32 and with the enclosure alone.
- [base.stl](../enclosure/stl/base.stl), [lid.stl](../enclosure/stl/lid.stl): individual print-oriented parts.
- [case-fastener-coupon.stl](../enclosure/stl/case-fastener-coupon.stl): exposed-nut M2 × 20 stack with Ø4.2/4.4/4.6 head entries.
- [board-fastener-coupon.stl](../enclosure/stl/board-fastener-coupon.stl): exposed-nut M1.6 × 6 stack with Ø3.4/3.6/3.8 head entries and a nominal PCB-thickness stand-in.
- [fit-coupon.stl](../enclosure/stl/fit-coupon.stl): switch openings 14.0/14.1/14.2 mm.
- [usb-fit-coupon.stl](../enclosure/stl/usb-fit-coupon.stl): 30 × 42 × 14 mm registered PCB cradle that reproduces the socket collar and mounting positions for a real seating test.

From the repository root:

```sh
/Applications/Blender.app/Contents/MacOS/Blender --background --factory-startup --threads 4 --python enclosure/build.py -- --export
/Applications/Blender.app/Contents/MacOS/Blender --background --factory-startup --threads 4 --python enclosure/check-assembly.py
/Applications/Blender.app/Contents/MacOS/Blender --background --factory-startup --threads 4 --python enclosure/print-layout.py
```

The generator updates Blender, OpenSCAD, individual STLs and diagrams. Rebuild combined plates afterward. The independent checker verifies hardware direction/length, exposed nut access, bottom head entries, bearing material, four PCB contacts, and nominal component clearances. USB checks verify the collar, PCB relief, metal-plug path and the overmold path conditional on the required shoulder position. The registered cradle verifies the physical cable separately. The generated validation reports record the latest results and source hashes. Reports do not establish actual print strength or clone fit.

## Print and assemble

1. Use the revised **base and lid together**; do not mix with the old captive-nut parts. For the Bambu A1 with a 0.4 mm nozzle, use PLA, four walls and five floor layers, about 0.16 mm layers for the base and USB coupon and 0.10–0.12 mm for the lid and other coupons. Use the same settings for the USB coupon and base so the fit comparison is meaningful. Inspect small counterbore bridges and the USB opening in the slicer.
2. Test the fastener coupons with the actual new-length screws. Heads should pass freely, and nuts should engage fully on their open top surfaces. Print the USB cradle floor-down, mount the actual board using its two holes, and compare cable seating against the bare board. The plastic cable shoulder must not stop short on the collar. Inspect the small lower lip and opening's upper edge before checking fit.
3. With USB unplugged, seat the board on all four supports. Verify the two USB-end pads contact bare board and do not press on solder. Align the two existing mounting holes.
4. Insert the **M1.6 × 6 screws from underneath**, place the M1.6 nuts openly on top of the PCB, hold each nut and tighten gently. Check the board remains flat and all GPIO pads/wires clear the supports.
5. Seat the switch and lid, leaving wire slack for service. Insert **M2 × 20 screws from underneath** and fit the two M2 nuts openly on the lid. Hold the nuts while tightening; stop if the lid does not sit freely. Press the keycap on after tightening.
6. Add feet at the relocated corner recesses. All four screw entries must remain accessible. Check key travel, connector insertion/removal and board flex, then reconnect USB.

## RESET / BOOT service access

**The first version uses disassembly, with no exterior button holes or extra
parts.** The two underside case screws remain clear of the feet. Remove those
screws and lift the lid with its switch and keycap still attached; the cap does
not need removal just to open the case. Support the lid beside the base rather
than leaving it hanging from its wires.

RESET restarts the board. BOOT (marked **0** on some S2 Minis) selects the ROM
downloader when held during reset. Hold BOOT, tap/release RESET, then release
BOOT once the USB downloader appears. See the [LOLIN instructions](https://docs.wemos.cc/en/latest/tutorials/s2/get_started_with_arduino_s2.html)
and [firmware flashing guide](../firmware/README.md#flash). This firmware disables
the serial-line reboot shortcut, so physical access is needed for later uploads
as well as first assembly. A routine restart can also be done by unplugging and
reconnecting USB, with BOOT released.

1. Quit the companion and disconnect USB before opening the case.
2. Remove the two case screws, support the lid, and expose the USB end of the
   board. Locate the actual RESET and BOOT actuator faces using the board labels.
   The current Blender references show side-facing buttons near the USB end;
   exact positions and travel on the purchased clone remain unmeasured.
   The nominal side gaps are about **8.75 mm at RESET** and **7.75 mm at BOOT**,
   with the actuator centres about **12.15 mm below the rim**. This favors a
   narrow tool over fingers. The modeled channels lie behind the electrical
   header rows and clear the case posts; keep wires out of these channels.
3. Confirm a finger or blunt nonconductive tip can reach each actuator without
   levering against the PCB or pulling the wire joints. Do not force a tool
   through the USB opening. If access is awkward, unplug USB and remove the two
   PCB mounting screws too; service the supported board outside the base.
4. Reconnect USB only once the board and lid are stable on a nonconductive work
   surface. Perform the BOOT/RESET sequence and upload. Disconnect USB again
   before refitting any screws and closing the case.

**Assembly acceptance check:** before finalizing wire lengths, demonstrate this
opening and flashing sequence. Leave enough service slack for the lid to clear
the buttons and be supported beside the base, and make sure that same slack
fits inside without touching clips, pins or screw posts. The wires in Blender
are illustrative routes, not a validated service loop. Lid-off finger/tool
access and board flex are also not yet physically verified.

If closed-case access becomes necessary, investigate **two recessed side-wall
holes**, aligned to the measured lateral actuators. Bottom holes cannot provide
a direct route through the PCB, and top holes do not align with these modeled
side-facing plungers. Hole locations, tool clearance and a travel limit must be
checked on the actual board before changing the printable base; no hole diameter
or location is released as fabrication-ready yet. Preserve access to both
controls and keep the GPIO pads and USB connector clear.

No headers, battery, hot-swap socket or extra circuit board are included in this envelope.

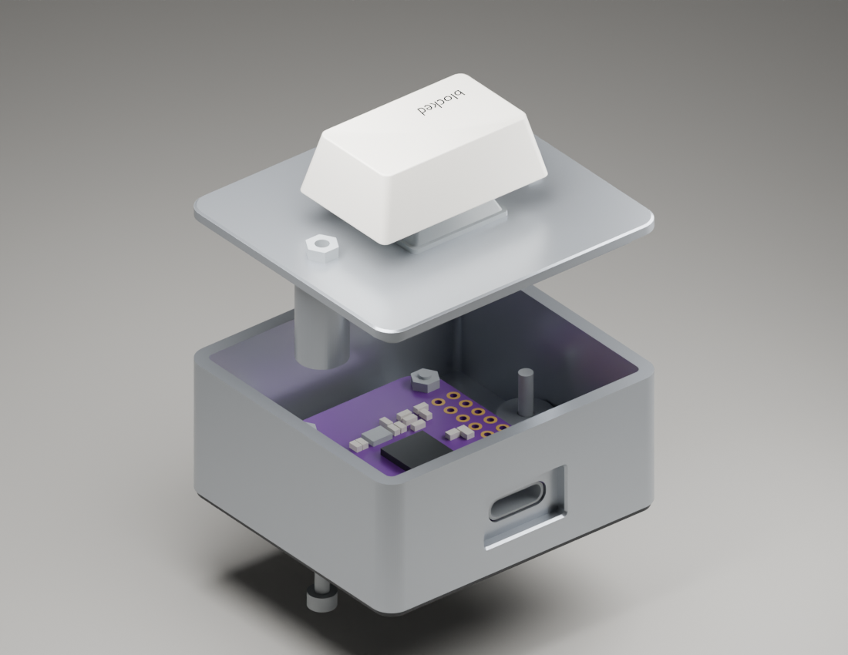
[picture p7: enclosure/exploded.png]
Exploded Blender assembly


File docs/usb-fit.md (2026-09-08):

# USB-C socket collar and fit cradle

The revised **9.6 × 3.6 mm rounded opening, R1.65**, follows the nominal **9.2 × 3.2 mm, R1.45** metal socket with **0.2 mm clearance per side**. Its center is z = 8.7 mm. This is a socket-shaped collar inside a recess, replacing the previous plug-sized through-hole.

A **13.5 × 7.6 mm outer recess**, R0.7, gives the cable body room to approach the collar. Its exterior lead-in is 0.4 mm deep and widens by 0.25 mm per side. Four PCB supports and all bottom-entry screws are retained.

**Prototype fit condition:** the fully seated cable's plastic shoulder must sit at least **0.35 mm ahead of the actual socket lip**, assuming the modeled socket position. This is a required clearance, not a measurement of the user's cable. The physical board and seated cable must be tested before treating this as a confirmed fit.

## What the primary sources establish

The [USB-IF Type-C Cable and Connector Specification, Release 2.4, October 2024](https://e2e.ti.com/cfs-file/__key/communityserver-discussions-components-files/196/USB-Type_2D00_C-Spec-R2.4-_2D00_-October-2024.pdf), hosted by Texas Instruments, gives these interface dimensions:

| Feature | Specified dimension | Location |
| --- | --- | --- |
| Plug metal width | 8.25 ± 0.03 mm | Figure 3-3, page 54 |
| Plug metal height | 2.40 ± 0.03 mm | Figure 3-3, page 54 |
| Plug metal length | 6.65 ± 0.10 mm | Figure 3-3, page 54 |
| Exposed plug shell | 6.51 mm minimum | Figure 3-3, page 53 |
| Plug overmold envelope | 12.85 mm maximum × 7.0 mm maximum | Figure 3-3, page 54 |
| Fully seated overmold-to-product clearance | 0.05 mm minimum axial gap; 0.05 mm each side in a recess | Informative Figure 3-82, page 147 |

The [USB-IF specification landing page](https://usb.org/usb-type-cr-cable-and-connector-specification) describes the standard and links its document library. The older 12.35 × 6.5 mm overmold allowance is not the envelope used here.

These dimensions do **not** identify the clone's receptacle. The [official WEMOS schematic](https://docs.wemos.cc/en/latest/_static/files/sch_s2_mini_v1.0.0.pdf) labels it `USB_C_16P`, without a connector manufacturer's part number. A receptacle's outside shell, PCB mounting height and length depend on the selected part. For example, [GCT USB4105](https://gct.co/connector/usb4105) has a published 3.31 mm profile and 7.35 mm body length; an [Amphenol receptacle drawing](https://cdn.amphenol-cs.com/media/wysiwyg/files/drawing/10168357.pdf) shows an 8.94 × 3.16 mm shell. Neither part is confirmed on the user's board.

USB-IF §3.2.1, note 7, printed page 46 recommends a **6.20 ± 0.20 mm effective receptacle shell length at system level**. This does not grant a universal 0.30 mm forward bezel allowance. The collar therefore remains conditional on the measured cable shoulder position.

## Collar depth and PCB clearance

The nominal PCB edge is at y = 18.65 mm and socket lip at y = 18.95 mm. The collar face sits at **y = 19.25 mm**, 0.30 mm ahead of that lip and 1.75 mm behind the case exterior. The cable shoulder must remain at or beyond y = 19.30 mm to provide 0.05 mm axial clearance.

The reinforced frame extends back to y = 18.05 mm. A backside PCB-edge relief ends at y = 18.75 mm, spanning z = 5.3–7.3 mm. It clears the nominal board and leaves a **0.5 mm lower lip**; the top and sides retain 1.2 mm depth. Inspect the small lip in the slicer and after printing. It must not press on the PCB or socket.

The actual socket's outer profile, height above the board and 0.3 mm overhang remain photo-derived assumptions. The collar's 0.2 mm clearance is a starting print allowance. It is not a zero-clearance press fit, nor proof that every clone or cable fits.

## Test the fit cradle before printing the case

[usb-fit-coupon.stl](../enclosure/stl/usb-fit-coupon.stl) is now a **30 × 42 × 14 mm cradle** with the same four PCB supports, two mounting holes, recessed collar and rear opening as the case. It replaces the previous three-hole cable gauge. Registering the actual board on its mounting holes lets this print test both the socket outline and cable seating depth.

1. On the Bambu A1, print the cradle floor-down with the same filament, nozzle and layer settings intended for the base. With a 0.4 mm nozzle, start with PLA, 0.16 mm layers and four walls. Inspect the thin collar lip and bridge above the port in the slicer; print dimensions are subject to extrusion and shrinkage.
2. With USB disconnected, rest the actual board on all four pads. Use the same two M1.6 × 6 mm bottom-entry screws and exposed M1.6 nuts. Do not pull the board into alignment by tightening the nuts.
3. The socket should enter the rounded collar freely, without bending the board or rubbing the metal shell. Check the underside relief clears the PCB and solder joints.
4. Compare the cable's fully seated position in the bare board against its position in the cradle. The plastic shoulder must not bottom against the collar before the plug seats. Check both plug orientations and USB enumeration. Enumeration alone does not prove full seating.
5. If the collar is tight or blocks seating, stop and update its dimensions from measurements before printing the full case. A tighter profile must not be obtained by forcing the connector against the board.

The combined STL with coupons includes this cradle. The nominal geometry audit checks the required shoulder plane and plug path; it explicitly does not certify that the actual cable meets that plane.

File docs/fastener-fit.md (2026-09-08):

# Exposed-nut fastener audit

This revision replaces the covered nut traps after feedback from the assembled prototype. Every screw enters from the bottom; every nut rests on an open top surface. The board nuts are exposed when the lid is removed, and case nuts are exposed on the lid.

## Nominal stack

All dimensions are millimetres; screw length is measured under the head.

| Feature | PCB | Case |
| --- | --- | --- |
| Quantity | 2 screws + 2 nuts | 2 screws + 2 nuts |
| Screw | **M1.6 × 6**, pitch 0.35 | **M2 × 20**, pitch 0.4 |
| Head envelope diameter × height | 3.2 × 1.7 | 4.0 × 2.1 |
| Bottom entry diameter | 3.6 | 4.4 |
| Head bearing height | z = 2.8 | z = 4.4 |
| Head bottom | z = 1.1 | z = 2.3 |
| Continuous plastic over head recess | 2.7 to PCB underside | 1.8 to local pad top |
| Nut bearing surface | PCB top z = 7.1 | Lid top z = 22.0 |
| Nut assumed AF × thickness | 3.5 × 1.3 | 4.0 × 1.6 |
| Nut top | z = 8.4 | z = 23.6 |
| Screw tip | z = 8.8 | z = 24.4 |
| Nominal protrusion beyond nut | **0.4** | **0.8** |
| Shaft clearance diameter | 1.8 in base, existing 2.0 PCB hole | 2.2 |

For both families: `tip = head_bearing_height + under_head_length` and `protrusion = tip − nut_top`. The modeled screws fully traverse the nut thickness. There is no blind screw-tip cavity. The case guide posts stop at z = 6.5, leaving 0.3 mm above the base pads; the case rim sets closure height.

The old **M1.6 × 4 / M2 × 8 screws are too short for these released stacks**. Check the [ordered Maierke kit](https://www.amazon.com/dp/B0GKFMJH24?th=1) for the new lengths; their inclusion has not been verified. Nut size/head geometry remain reference assumptions. Standard M1.6 nuts can have 3.2 mm rather than the kit-listed 3.5 mm flats; exposed seating removes dependence on a tight hex pocket, but nut bearing coverage and thickness still need checking.

Reference head envelopes and drives come from [Monster Bolts M1.6](https://monsterbolts.com/pages/m1-6-bolt-size), [M2](https://monsterbolts.com/pages/m2-bolt-size), and [Accu M1.6](https://www.accu.co.uk/metric-cap-head-screws/250388-SSCF-M1-6-3-A2-R360). Nut thickness ranges are recorded by [Westfield DIN934](https://www.westfieldfasteners.co.uk/Standards/Nut_Hex_M.html). These references do not certify the actual kit.

## Access and support

Hold the exposed nuts with fine pliers while using a 1.5 mm hex key from underneath. Remove the keycap for case-nut gripping: the approximately 0.69 mm nominal lateral cap gap is component clearance, not assured tool clearance. No captive slots, glue, heat-set inserts or washers are used.

Feet move to x = ±17, y = ±15, keeping the new PCB head entries clear. All four PCB support tops are at z = 5.5. Two screw posts use the documented mounting holes; two plain 2 × 1 mm USB-end contacts sit at (−9.5,17.9) and (11,17.9), based on bare regions in the official underside photo. Verify those regions against the actual clone and solder.

The independent Blender checker tests screw/nut dimensions and orientation, full engagement, bottom access, open vertical nut paths, continuous bearing material, four support contacts, GPIO clearance and component interference. It does not model real threads, nut chamfers, print distortion, solder joints, tightening torque, or cable load strength.

## Fit before final assembly

Print the updated fastener coupons in the case material/settings. Their middle station matches the nominal head bore; outer stations vary it by ±0.2 mm. Check actual screw length, free head entry, full nut engagement and flat PCB seating. Tighten gently while holding the nut; do not use tightening force to flatten a rocking board or an obstructed lid. Test BOOT/RESET access with the lid removed and inspect the four supports during cable insertion/removal.

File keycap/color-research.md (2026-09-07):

# White Apple keyboard legend color

Research date: September 7, 2026.

**No public Apple ink formulation, Pantone reference, measured CIELAB target,
or official sRGB legend specification was found.** The final upload uses
**sRGB #8B8B8B (139, 139, 139)** as a photo-based visual match, not an exact
Apple manufacturing specification. This replaces the earlier unsampled
design choice #6E6E73.

## Specification search

Apple's [Magic Keyboard technical specifications](https://support.apple.com/en-ca/121955)
do not publish a legend-color target. Its
[recycler guide](https://www.apple.com/recycling/recycler-guides/pdf/products/accessories/Magic_Keyboard_Recycler_Guide_English.pdf)
describes material categories, and its
[Regulated Substances Specification](https://www.apple.com/environment/pdf/Apple_Regulated_Substances_Specification.pdf)
addresses chemical restrictions; neither supplies a keyboard legend ink/color recipe.
These sources do not establish the exact marking process for this keyboard, either.

## Four reference images inspected

| Reference | Sampled legends | Median pixel RGB values |
| --- | --- | --- |
| [Apple official MJLX4 product image](https://store.storeimages.cdn-apple.com/1/as-images.apple.com/is/MJLX4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), from the [Magic Keyboard product page](https://www.apple.com/shop/product/mjlx4ll/a/magic-keyboard-usb-c-us-english) | Q, A, control | (139,139,139), (139,140,140), (139,139,139) |
| [F. Kawabata's close-up](https://note.com/kawabata/n/n1211c0fff562) | Q, A, tab | (79,84,82), (73,78,77), (85,90,91) |
| [Applesfera keyboard close-up](https://www.applesfera.com/tutoriales/como-borrar-texto-adelante-nuestro-mac-ipad) | Q, A, tab | (121,122,127), (120,120,126), (148,149,154) |
| [AppleInsider keyboard photograph](https://appleinsider.com/inside/iphone/tips/how-to-access-extended-characters-like-the-degree-symbol-on-iphone-and-mac) | shift, return, delete | (133,135,128), (118,121,113), (107,109,97) |

The official image provides a consistent neutral-gray target and the largest
image for sampling. The other photographs show substantially different
exposure, color casts, focus and viewing angles. Their nearby white key
surfaces differ too. The Applesfera image also uses an older key/font style,
so it is only a general gray-on-white appearance reference. These are not
four calibrated measurements of one identical physical object.

The chosen #8B8B8B follows the recurring official-image median. It is **not**
an average of all photos or a claim that photographed RGB reveals an ink formula.

## Sampling method and limits

[color-samples.json](color-samples.json) records original image URLs, SHA-256
digests, dimensions, all 12 legend/white-patch rectangles, thresholds and results.
Images were downloaded temporarily for analysis and are not redistributed here.
Coordinates refer to the original image pixels, with the origin at top-left.

For each hand-selected legend rectangle, take a nearby clean key-surface patch.
Compute its median RGB and weighted encoded-RGB luminance
`0.2126 R + 0.7152 G + 0.0722 B`. Select legend-rectangle pixels below 75% of
that patch luminance, then calculate their per-channel medians. This excludes
the white key background and many antialiased edge pixels. It does not remove
all blur, JPEG artifacts, reflections or lighting effects. The threshold is
an analysis heuristic, not a calibrated reflectance measurement. None of the
downloaded images contained an ICC profile; sRGB was assumed.

An exact physical color match would require a measured reference key or an
Apple manufacturing color target, followed by the printer matching the color
on its actual white keycap material. A hex value alone cannot specify the ink,
coating, substrate or printer profile. No CMYK or Pantone equivalent is claimed.

## Order instruction

Use the current SVG or PNG, select **White / TOP Print only / R3 1x1.5 Tab**, and
ask the vendor:

> Print the supplied lettering in neutral gray, targeting sRGB #8B8B8B on the
> white keycap. This is an Apple-keyboard-inspired photo match, not a Pantone
> specification. Preserve the supplied type shapes and lower-left placement:
> word 9 mm wide, visible ink about 2 mm from the usable left and front edges
> of the TOP surface. Please provide a placement/color proof before printing.

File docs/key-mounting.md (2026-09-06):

# Switch and Tab keycap mounting

The key uses a **plate-mounted Gateron Baby Kangaroo 2.0 and a single centred MX socket in the 1.5u Tab cap**. The lid carries the key's mechanical loads; the electrical wires and ESP32 board do not support it. No additional screws, glue, stabilizer, switch PCB or hot-swap socket are required by this design.

**Prototype status:** the plate, ribs and service clearances are designed here. The purchased switch's clip details and the Max Keyboard cap's socket are explanatory references where exact dimensions are unavailable. Fit must be checked using the actual switch and cap.

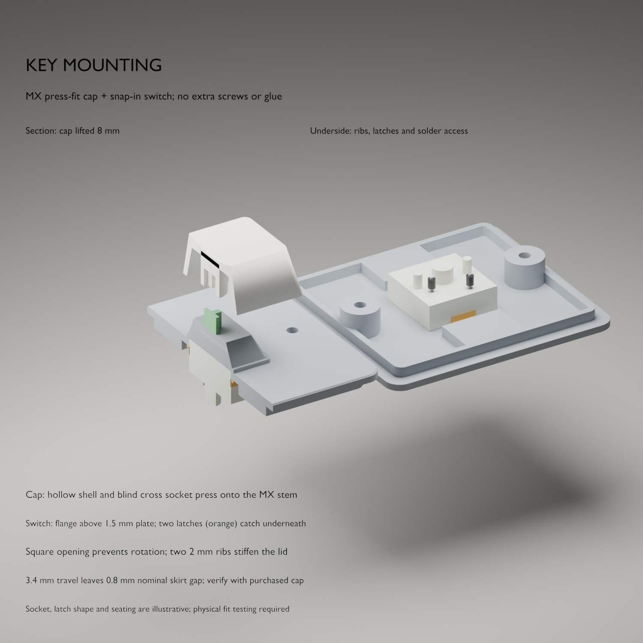
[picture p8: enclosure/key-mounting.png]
Section through the key mounting


## What holds each part

| Interface | Retention and load path | Release / inspection |
| --- | --- | --- |
| Cap → moving stem | The cap's moulded cross socket presses onto the switch's MX cross. The cross transmits off-centre presses and resists rotation. | Pull the cap straight upward while supporting the switch housing; do not lever against the lid or twist the stem. |
| Switch → lid, downward | The housing flange rests on the top face around the square aperture. Pressing force passes from flange into lid. | Flange must sit flat on every side, with no trapped wire or print debris. |
| Switch → lid, upward | Two spring clips on opposite sides of the switch latch beneath the plate. They prevent the switch lifting out during use. | Remove the lid and compress the switch's plate-retaining clips, then push the housing up through the aperture. Do not confuse them with the housing-disassembly tabs. |
| Switch → lid, sideways | The square body fits the square aperture and limits rotation and lateral movement. | Tune aperture fit using the coupon; a loose switch is not fixed by tightening the case screws. |
| Lid → enclosure | Two underside ribs stiffen the deck near the key. The perimeter skirt registers the lid, and the existing M2 case screws retain it. | Remove the two screws underneath and lift the lid only as far as the wire service loop allows. |

The flange and clip arrangement is the standard plate-mount mechanism. The five-pin switch's three plastic locating posts are intended for a keyboard PCB; they remain free in this hand-wired build. The two metal pins carry electrical connections only. See the [Gateron drawing](https://gateron.com/u_file/2308/29/file/GATERONBabyKangaroo20Switch-b4b5.pdf) and [Gateron's switch-removal guidance](https://www.gateron.com/blog/detail/gateron-3-in-1-customization-tool).

## Plate and reinforcement

| Feature | Nominal design |
| --- | --- |
| Manufacturer aperture specification | 14.00 mm +0.05/−0.02; actual target 13.98–14.05 mm |
| Printed aperture CAD | 14.1 × 14.1 mm initially; coupon alternatives 14.0 / 14.1 / 14.2 mm compensate for the printer |
| Manufacturer plate specification | 1.50 mm +0.01/−0.05; actual target 1.45–1.51 mm, kept free of underside ribs |
| Switch flange | 15.9 × 15.7 mm from the Gateron drawing |
| Flange overlap at 14.1 mm opening | Approximately 0.9 mm per side in x and 0.8 mm per side in y |
| Reinforcing ribs | Two integral 12 × 9.1 × 2 mm ribs, centred at x = 0, y = ±14.05 mm |
| Rib position | Below the plate, extending toward the front and rear registration skirt; clear of the electrical header columns |
| Switch travel | 3.4 mm maximum for the selected Baby Kangaroo 2.0 |

These aperture and plate tolerances come from the recommended-mounting section of the [Gateron specification](https://gateron.com/u_file/2308/29/file/GATERONBabyKangaroo20Switch-b4b5.pdf). **14.1 mm is a CAD starting value for print compensation, not the manufacturer's specified finished opening.** Measure the printed coupon and clip land.

The aperture remains square and its bearing edges are not enlarged for a decorative chamfer. A thicker plate directly under the switch clips can prevent them from latching, so reinforcement sits farther away. Rib stiffness and latch retention still need a physical test; mesh clearance is not a strength calculation.

The cap is removable and has no added rigid guide around its skirt. A guide sized from an approximate keycap model could rub or jam at full travel. The intended 1.5u cap uses one centred switch; confirm the purchased cap's socket position and test both ends. The [Omnitype size table](https://intercom.help/omnitype/en/articles/5121683-keycap-sizes) lists 1.5u Tab without a stabilizer; a conventional 2u stabilizer is not part of this layout.

## Fit, solder and assemble

1. Print the [switch coupon](../enclosure/stl/fit-coupon.stl) with the intended filament and lid settings. It reproduces the 1.5 mm clip land. One/two/three notches identify the 14.0/14.1/14.2 mm apertures.
2. Insert the bare switch from above. Select the opening that lets the flange sit flat and both clips spring fully beneath the plate. Check from below. The housing must not rock or lift with a gentle upward pull. Reject a fit requiring excessive force or leaving either latch compressed.
3. Try the cap on the coupon-mounted switch. Support the housing and press straight over the stem. Check free return after full presses at the centre, left and right ends. Confirm the cap seats securely and does not touch the plate or switch housing during travel. Do not glue the socket or sand the switch stem to compensate for a mismatched cap.
4. Update `switch_opening` from the coupon result, regenerate, and print the lid top-down. The two ribs are integral to the lid. Keep the clip land clean and check its actual thickness; do not thicken it with adhesive or paint. Test the M2 fastener coupon and slide the lid's two M2 nuts into their pockets before adding the switch or wires, following the [enclosure guide](enclosure.md).
5. Clip the switch into the lid **before soldering**, with the light-guide side toward the rear/USB side as shown in Blender. Support the lid with the stem free of pressure. Follow the [wiring guide](hardware.md), insulate both metal terminals and keep the clips accessible.
6. Route enough wire slack to lift the lid for service. The loop must not pull on the terminals or run through a clip, screw, key-travel region or PCB mounting hole. Dry-fit the lid and check at least 2 mm between exposed switch joints and board components.
7. Close the case with its existing M2 screws, then install the cap while supporting the assembly. Test repeated centre and off-centre presses and inspect the flange for movement. Check for lid flex, stem sticking, skirt rubbing or incomplete return. If any occurs, reopen and correct the fit before use.

For maintenance, unplug USB and remove the cap while supporting the switch. Open the case, support the lid, and release both plate clips from below to remove the switch. Desolder its wires if replacing it. Never use the wires or solder pins as handles. A keycap puller or switch puller is optional; it does not replace checking the clips from below on this hand-wired assembly.

## What the Blender view proves

The section shows the mounting sequence and the nominal plate/rib geometry. Separate references show the cap at rest and after 3.4 mm of travel, plus space for reaching the clips with the lid removed. The independent [assembly check](../enclosure/assembly-validation.json) checks the modeled case, rib and access clearances.

The current illustrative cap has a nominal 0.8 mm skirt-to-lid gap at full travel. Its moulded socket dimensions, seating depth and nesting around the switch's upper housing are **not manufacturer-verified**. This is not a printable keycap or a guarantee that the selected cap clears. Obtain the [missing dimensions](../keycap/dimensions-request.md), or measure a blank from the same mould, before declaring exact fit. The switch's own mechanism determines end of travel; the lid must not become the travel stop.

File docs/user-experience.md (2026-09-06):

# Install, plug in, press

The recipient gets an assembled, pre-flashed button and one Mac app. They should
never need Arduino, Xcode, Homebrew, a terminal, a serial-port name, or a GitHub
token pasted into settings.

## First use

Install/open Blocked → connect GitHub if necessary → allow Chrome access →
enable the button → plug it in → press on a Chrome PR.

Setup explains the exact action and identifies the GitHub account before enabling
it. Existing GitHub CLI credentials are reused. Otherwise the app shows a device
code and opens GitHub's authorization page. GitHub's page identifies the client
as GitHub CLI; no separate Blocked OAuth app is registered. Chrome's macOS
Automation consent cannot be bypassed. Startup at login is visible and optional.

## Everyday use

- Plugging in connects automatically. A held key or reconnect never submits.
- A fresh press on the focused Chrome PR sends the configured review. The default
  is **Request changes**, body **blocked**.
- Brief feedback confirms success or explains a failure without stealing focus.
- Enable/pause is remembered across restarts. No per-launch rearming or per-review
  confirmation is required. The menu exposes Pause and the full last result.
- Custom actions and troubleshooting overrides live in Settings. Changing them
  asks the user to enable the new configuration once.
- Firmware flashing and RESET/BOOT access are the maker's service tasks, not
  recipient onboarding. Ship it flashed, with a known data cable.

## Implemented versus still to prove

| Part | State |
| --- | --- |
| Native setup window, account display, device-code sign-in | Implemented; fake-process tests and native layout check pass |
| GitHub helper included for Intel and Apple Silicon | Implemented, pinned official binaries and checksums, MIT notices included |
| Remember enable/pause; automatic USB rediscovery | Implemented; activation/protocol logic tested; real hardware reconnect still pending |
| Optional launch at login | Implemented using SMAppService; actual registration/approval on recipient Mac not tested |
| Nonactivating success/error feedback | Implemented; full Chrome-focus interaction still needs live validation |
| Chrome permission and front-window/tab reader | Implemented; live foreground-window smoke test remains unresolved on this host |
| Signed, notarized downloadable installer | Not yet produced; current build uses ad-hoc signing |
| Clean Mac with no gh, existing-gh Mac, revoked permissions, restart/wake, USB reconnect and one authorized real review | Acceptance testing still required |

The development scripts build the app; they do not register login items, sign in,
submit reviews or publish a release. Tests do not alter the user's GitHub account.

Primary platform references: [Apple main-app login service](https://developer.apple.com/documentation/servicemanagement/smappservice/mainapp),
[Apple registration/approval](https://developer.apple.com/documentation/servicemanagement/smappservice/register()),
[GitHub CLI device-flow implementation](https://github.com/cli/cli/blob/v2.100.0/internal/authflow/flow.go),
[GitHub CLI release provenance](../companion/ThirdPartyNotices/GitHubCLI.md).

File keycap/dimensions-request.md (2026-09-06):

# Dimensions needed for the custom Tab keycap

This request is ready to copy to Max Keyboard; it has not been sent.

> I am designing a small enclosure around one of your custom printed keycaps, selected as **R3 1x1.5 (Tab / |), White, TOP Print only**, with the legend `blocked`.
>
> Could you provide a STEP model or a dimensioned mechanical drawing of this exact keycap? I need the outer width/depth, front and rear heights, top-surface profile, inner skirt envelope, and the MX stem socket's centre position, depth and height relative to the bottom rim. I also need the seated height and skirt clearance at full travel on a standard Gateron MX-style switch.
>
> If CAD is unavailable, could you confirm these dimensions and tolerances? Please also indicate whether any provided CAD can be included in an open-source enclosure repository, or should remain a local reference.

An unprinted blank of the exact same mold can also be measured before ordering the custom legend. A generic OEM or Cherry-profile model does not establish these dimensions for Max's selected cap.

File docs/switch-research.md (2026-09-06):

# Switch research

The selected build uses the Baby Kangaroo 2.0. These are alternatives for future builds; the canonical shopping list is [BOM.md](../BOM.md).

| Choice | Feel and action | Enclosure/keycap impact |
| --- | --- | --- |
| **Gateron Baby Kangaroo 2.0 — gift recommendation** | Strong early tactile bump; manufacturer rates operation at 59 ± 8 gf. | Five-pin MX structure, same two-contact wiring. Validate plate coupon and cap clearance. [Manufacturer](https://www.gateron.com/products/gateron-baby-kangaroo-20-tactile-switch-set), [drawing](https://gateron.com/u_file/2308/29/file/GATERONBabyKangaroo20Switch-b4b5.pdf) |
| **Kailh BOX White — crisp click** | Click bar, nominal 45 gf operation and 55 gf tactile force, 3.6 mm total travel. | Standard-height MX-style option; sample first if noise matters. [Manufacturer](https://www.kailh.net/collections/all-products/products/kailh-box-switch-set) |
| **Kailh BOX Jade — emphatic click** | Thick click bar, nominal 50 gf operation and 75 gf tactile force, 3.6 mm total travel. | A firmer, louder-feeling choice for the joke; verify snap fit. [Manufacturer](https://www.kailh.net/products/kailh-box-thick-clicky-switch-set) |
| **CHERRY MX2A Brown — mild alternative** | Soft tactile bump; 2 mm to actuation, 4 mm total. | Standard MX plate and cap. [Manufacturer](https://www.cherry.de/en-us/product/mx2a-brown) |
| **CHERRY MX2A Blue — familiar click** | Tactile and audible click; 2.2 mm pre-travel, 4 mm total. | Same standard MX family; validate the snap fit with the coupon. [Manufacturer](https://www.cherry.de/en-us/product/mx2a-blue) |
| **Kailh Choc V2 Brown — thinner redesign** | Tactile; 1.3 ± 0.3 mm pre-travel, 3.2 ± 0.25 mm total, nominal 45 ± 10 gf operation. | Requires a Choc-specific mounting redesign and verified cap clearance. An MX-style stem does not make the whole housing MX-compatible. [Manufacturer](https://www.kailh.net/products/kailh-choc-v2-low-profile-switch-set) |

The included enclosure targets standard MX. Low-profile switches save less overall height when the S2 Mini remains stacked underneath; a side-by-side board layout can make a flatter but wider version. Do not substitute Choc V1 caps or mounts for V2 by assumption.

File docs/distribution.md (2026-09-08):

# Sharing the macOS app

`companion/scripts/package-release.sh` creates one DMG containing `Blocked.app`, an Applications shortcut, and recipient instructions. The app includes the pinned GitHub CLI for Intel and Apple Silicon; recipients need macOS 13 or newer, Chrome, and their own GitHub account. They can install and complete setup without Terminal or Homebrew. The physical button must already have compatible firmware.

## Private beta

After the app's source changes and tests are complete, run from the repository root:

```sh
companion/scripts/package-release.sh --offline
```

`--offline` uses the existing verified GitHub CLI archive cache. Omit it to allow missing archives to download. The script builds a fresh universal app, verifies its bundled executable and license, checks code signatures, then mounts the finished DMG read-only to check its contents. Only generated app files and the checked-in recipient text are staged; no Keychain items, GitHub configuration, or app preferences are copied.

The output is `companion/dist/Blocked-0.3.0-beta.dmg`, with a SHA256 sidecar. Send the DMG itself. The beta uses ad-hoc signing by default and is **not Apple-notarized**. After trying to launch it, a recipient may need **System Settings → Privacy & Security → Open Anyway**. Managed Macs may prohibit that exception. See [Apple's first-open guidance](https://support.apple.com/en-us/102445). The current development machine has an Apple Development identity, which is not a Developer ID Application distribution identity.

The recipient drags the app into Applications and opens it there, signs in to GitHub, grants Chrome automation access, and optionally enables Open at Login. Existing sender sign-in state does not transfer. A beta DMG does not establish that Gatekeeper will accept the app on a fresh Mac; first-run setup and USB operation still require a recipient-machine test.

The 0.3.0 beta was built successfully with cached dependencies. Its mounted root contained exactly `Blocked.app`, `Applications`, and `Start Here.txt`. Both the app and bundled GitHub CLI passed Intel/Apple Silicon architecture checks; the delivered app passed strict signature verification and included its icon and both licenses. The DMG is 34,542,941 bytes. No notarization was requested or performed; its SHA256 is recorded beside it in `Blocked-0.3.0-beta.dmg.sha256`.

## Developer ID and notarization

For a future public release, obtain a **Developer ID Application** certificate and create a `notarytool` Keychain credential profile separately. Once those exist, explicitly request signing and notarization:

```sh
companion/scripts/package-release.sh --offline \
  --sign 'Developer ID Application: YOUR NAME (TEAMID)' \
  --notarize-profile YOUR_PROFILE
```

Add `--notary-keychain /path/to/your.keychain-db` only when the credential profile is stored in a specific Keychain. Credentials are read by Apple's tool; they are not command arguments or package contents. `--offline` only affects dependency downloads: an explicit notarization request uploads the app and DMG to Apple.

The script signs the nested GitHub CLI and app with hardened runtime and secure timestamps, submits the app archive, requires an `Accepted` response, staples and validates its ticket, then creates and notarizes the DMG. It also assesses the stapled app and DMG with Gatekeeper. A failed submission, timeout, rejected status, stapling failure, or verification failure aborts before publishing a new final DMG. Existing output from an earlier run remains unchanged; submission JSON is retained in `companion/dist/` for diagnosis.

Successful notarization produces `companion/dist/Blocked-0.3.0.dmg`. Using `--sign` alone still produces the `-beta` filename because it has not been notarized. The optional notarization path is implemented but has not been exercised with a distribution certificate or uploaded to Apple during this work. See [Apple's notarization documentation](https://developer.apple.com/documentation/security/notarizing-macos-software-before-distribution).

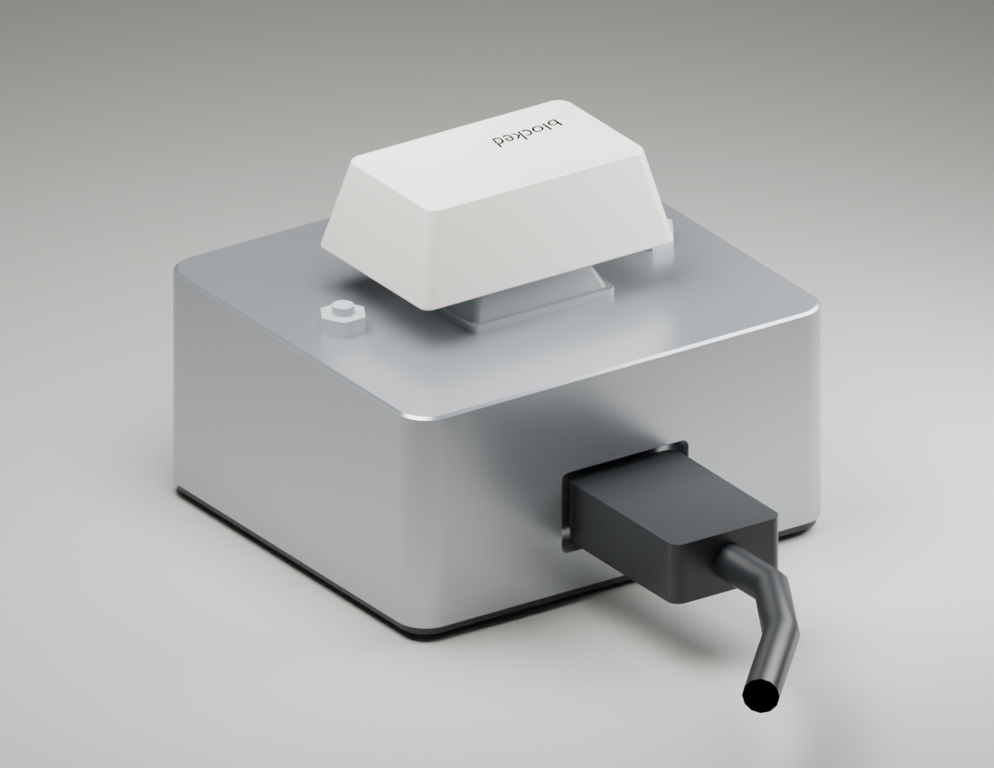
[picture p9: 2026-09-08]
enclosure/rear.png

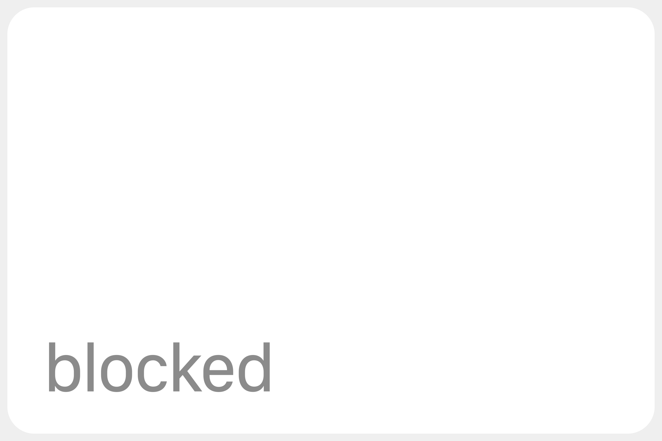
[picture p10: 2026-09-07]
keycap/blocked-tab-placement-preview.png

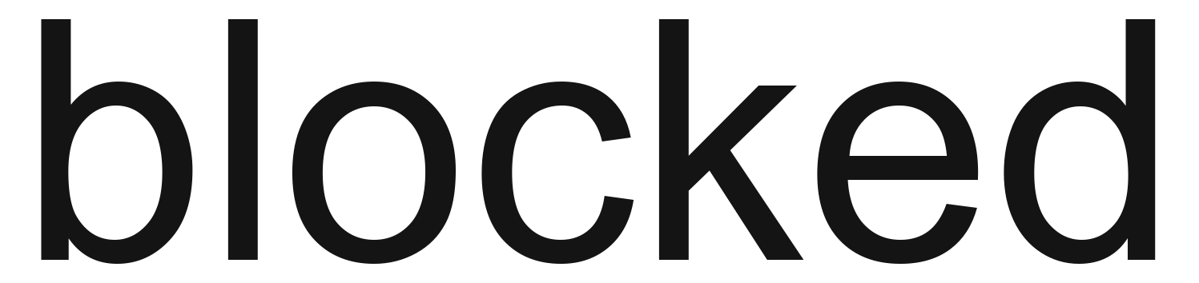
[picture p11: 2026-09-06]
keycap/blocked-artwork.png

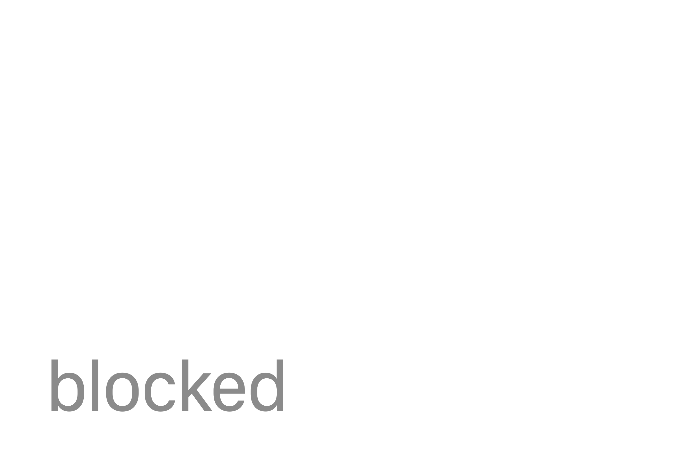
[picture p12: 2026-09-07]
keycap/blocked-tab-upload.png

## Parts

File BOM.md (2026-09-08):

# Shopping list — one blocked button

The revised enclosure uses **four bottom-entry screws and four exposed nuts**.
Reuse the nuts from your Maierke kit; check it for the new **M1.6 × 6 and M2 × 20**
screw lengths, whose inclusion has not been confirmed. No heat-set inserts are needed.
The fewest-orders route found is one Amazon checkout plus the custom Tab keycap
order; separate Amazon sellers may ship separate parcels. See the
[consolidated shopping plan](docs/amazon-shopping.md).

This is a prototype: measure the delivered fasteners and print the fit coupons
before the finished shell. [Fastener dimensions and fit checks](docs/fastener-fit.md).

## Remaining purchases

| Need | Direct product link | Exact selection / quantity |
| --- | --- | --- |
| 1 keycap | [Max Keyboard custom printed **1.5u Tab**](https://maxkeyboard.com/custom-art-icon-or-text-cherry-mx-keycaps.html) | **R3 1x1.5 (Tab / \|)**, White, TOP Print only; lowercase `blocked`. **$11**. [Artwork + settings](keycap/README.md). |
| 1 switch | [Gateron Baby Kangaroo 2.0 — Amazon](https://www.amazon.com/dp/B0CM347W2W) | **Baby Kangaroo 2.0, 10Pcs**, 5-pin MX style. **$7.99**; use one. |
| 4 feet | [METFUIN adhesive rubber sheets — Amazon](https://www.amazon.com/dp/B0FJ8WV32F?th=1) | **Black, 1/25 Thick 6X6 inch, two sheets**, **$6.99**. Cut four 8 × 8 mm pads with rounded corners. Selected thickness is nominally 1.016 mm; verify on delivery. |

Total: **$25.98 before shipping/tax**, assuming supplies below are already owned.
Prices and selections checked September 5, 2026; prices may change. The feet's
adhesive attaches to the case; exposed rubber grips the desk by friction.

## Mounting hardware — check the new lengths in your kit

| Use | Quantity per button | Source |
| --- | --- | --- |
| PCB mounting | **2 × M1.6 × 6 socket-cap screws + 2 × M1.6 nuts** | [Maierke 1050-piece kit](https://www.amazon.com/dp/B0GKFMJH24?th=1), nuts listed as 3.5 mm across flats |
| Case closure | **2 × M2 × 20 socket-cap screws + 2 × M2 nuts** | Same Maierke kit, nuts listed as 4 mm across flats |
| M3 assortment | None needed for this design | [Weideer kit](https://www.amazon.com/dp/B0DS8HYF64?th=1); keep for other projects |

Both screw lengths are measured **under the head**. Use a **1.5 mm hex key**
if the delivered sockets match the nominal sizes. No washers are used in this
stack. PCB screws pass through its two dedicated mounting holes; all 32 GPIO
holes remain separate. The switch's plate clips and the cap's MX socket need
no extra screws, stabilizer, hot-swap socket or circuit board.

## Buy only if missing

| Need | Direct product link | Selection / quantity |
| --- | --- | --- |
| Two wires + joint insulation | [Fermerry wire and heat-shrink bundle — Amazon](https://www.amazon.com/dp/B089CXFH4H?th=1) | **30 AWG-6C, 25FT per color**, **$10.29**. Includes 18 pieces of Ø2.4 mm tubing; verify it shrinks tightly enough to stay over each joint. Leave a lid service loop. |
| USB data cable | [UGREEN USB-C to USB-C — Amazon](https://www.amazon.com/dp/B0BPXKJSWY) | **1.6 ft, 3-pack**, USB 2.0 data. Use one; reuse a suitable existing cable first. Price not verified. |
| Hex driver | [Wera 05073593001 metric hex-key set — Amazon](https://www.amazon.com/dp/B009ODV0OE) | Includes **1.5 mm**; reuse an existing matching driver if available. Price not verified. |
| Solder | [Adafruit 0.5 mm rosin-core lead-free solder](https://www.adafruit.com/product/2473) | **$12.50 / 50 g**; only a small amount needed. Check the soldering kit first. |
| Filament | [Overture PLA, Metallic Gray](https://overture3d.com/products/overture-pla?variant=46749457744126) | **1.75 mm / 1 kg**, **$25.29**; reuse existing PLA/PETG and check printer compatibility. |

The wire bundle brings the total to **$36.27 before shipping/tax**. Other
optional supplies are excluded. Check that the USB plug seats fully through
the **16 × 10 mm rear opening**; data capability alone does not establish
mechanical fit.

## Already owned / print

- **Owned:** ESP32-S2 Mini ([your listing](https://www.aliexpress.us/item/3256812318584460.html); [LOLIN reference](https://www.wemos.cc/en/latest/s2/s2_mini.html)), soldering kit, 3D printer. The seller's board is not verified as manufactured by LOLIN.
- **Print first:** [switch coupon](enclosure/stl/fit-coupon.stl), [M2 case-fastener coupon](enclosure/stl/case-fastener-coupon.stl), and [M1.6 board-fastener coupon](enclosure/stl/board-fastener-coupon.stl).
- **Print after fitting:** [base](enclosure/stl/base.stl) and [lid](enclosure/stl/lid.stl). No paint is required.

[Mounting and assembly](docs/enclosure.md) · [Key mounting](docs/key-mounting.md) ·
[Wiring](docs/hardware.md) · [Measurements still needed](docs/component-accuracy.md).

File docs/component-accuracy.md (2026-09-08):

# Component dimensions and model accuracy

The enclosure now mounts the S2 Mini through its **two dedicated mounting holes**. The previous edge fingers were removed because the simplified board model did not expose the electrical pin layout. A clean intersection test against an empty PCB outline was insufficient.

The current references include more of the physical parts, but **the complete assembly is not yet an exact, measured model of the purchased hardware**. The table below separates published dimensions from derived coordinates and dimensions still needing measurement. The machine-readable record is [component-models.json](../enclosure/component-models.json).

## The selected board

The user supplied [AliExpress item 3256812318584460](https://www.aliexpress.us/item/3256812318584460.html). On inspection, the listing identified **Nextronics Store**, brand **XYCJJCXL**, and **S2 Mini V1.0.0**. Its photographs show a purple board with two large mounting holes at the antenna end and four columns of electrical headers. This is a visual match to the LOLIN layout, not confirmation that the seller uses LOLIN's exact PCB or components. The listing's AI-generated summary is not a mechanical specification.

| Feature | Model input | Evidence / confidence |
| --- | --- | --- |
| PCB outline envelope | 25.4 × 34.3 mm | Explicitly dimensioned in the [LOLIN drawing](https://docs.wemos.cc/en/latest/_static/files/dim_s2_mini_v1.0.0.pdf). Seller-board match still needs checking. |
| Dedicated mounting holes | Ø2.0 mm, 20.4 mm centre spacing, 2.5 mm side setback | Explicit dimensions in the same drawing; separate from the electrical holes. |
| Hole setback from antenna edge | Approximately 3.30 mm | Derived from vector geometry in the drawing, **not a dimension callout**. Measure before final printing. |
| Mount coordinates in the case | x = ±10.2 mm, y = −12.35 mm | Derived from that setback, with PCB centre y = +1.5 mm and USB toward +y. |
| PCB thickness | 1.6 mm provisional | Not specified by the available official mechanical drawing. Measure the actual board. |
| Electrical headers | 4 columns × 8 holes, nominal 2.54 mm pitch | [Official top photograph](https://docs.wemos.cc/en/latest/_static/boards/s2_mini_v1.0.0_1_16x16.jpg), [bottom photograph](https://docs.wemos.cc/en/latest/_static/boards/s2_mini_v1.0.0_2_16x16.jpg), and [schematic J2–J5](https://docs.wemos.cc/en/latest/_static/files/sch_s2_mini_v1.0.0.pdf). The nominal grid alignment and drill/pad diameters are reference inputs, not a manufacturer fabrication drawing. |
| USB socket, buttons, chip and passives | Photo-based positions and clearance envelopes | Their exact placements, package variants and assembled heights are not fully documented. Detailed appearance does not make those dimensions verified. |

No manufacturer-authored S2 Mini PCB/Gerber/STEP source was found in the [official documentation repository](https://github.com/wemos/docs). The [OpenHornet community footprint](https://github.com/jrsteensen/OpenHornet/blob/c259a65a1759801a2affea817fd99f6a14f1e1fe/ECAD/lib/OH_Footprints.pretty/S2_MINI.kicad_mod) is useful for comparison, but places the hole setback at 3.21 mm and offsets the outline from the header grid. It is not used as proof of manufacturer accuracy or imported into this project.

## Other components

| Part | What is supported | What remains unverified |
| --- | --- | --- |
| Gateron Baby Kangaroo 2.0 | Housing, mounting interface, locating posts, metal pins and travel are based on the [Gateron drawing](https://gateron.com/u_file/2308/29/file/GATERONBabyKangaroo20Switch-b4b5.pdf), part KS-9LKA10B059NW-D110. | Fine molded details, actual clip fit, solder blobs and the purchased switch's tolerances. The model is reconstructed from the drawing, not Gateron's original solid CAD. |
| Max Keyboard 1.5u Tab cap | The [vendor selection](https://maxkeyboard.com/custom-art-icon-or-text-cherry-mx-keycaps.html) specifies R3 1x1.5, MX compatibility and top printing. The [profile guide](https://maxkeyboard.com/mechanical-keycap-layout-and-size-chart.html) identifies OEM row profiles. | Exact outside dimensions, front/back heights, dish, skirt clearance and stem-socket position/depth. No exact CAD was found. The rendered cap remains an approximation; [vendor information request](../keycap/dimensions-request.md). |
| M2 × 20 case screws | Revised requirement: 20 mm under-head length; reference envelope Ø3.98 × 2 mm, 1.5 mm hex drive. [Dimension sources](fastener-fit.md). | Kit inclusion of this new length is unverified; head dimensions must be measured. Modeled threads/drive recesses are simplified. |
| M1.6 × 6 PCB screws | Revised requirement: 6 mm under-head length; reference envelope Ø3.14 × 1.6 mm, 1.5 mm hex drive. [Dimension sources](fastener-fit.md). | Kit inclusion of this new length is unverified. Actual head dimensions and PCB thickness control engagement. |
| Exposed hex nuts | Kit lists M1.6 nuts as AF3.5 mm and M2 nuts as AF4 mm. Thickness references and seating assumptions are recorded in the [fastener audit](fastener-fit.md). | Actual thickness, bearing coverage and printed strength need checking; exposed nuts are held with pliers. No heat-set inserts remain in the design. |
| Feet, wire and USB cable | Foot dimensions follow the cut-to-size BOM; wire paths and cable space show routing intent. | Cable overmold dimensions, exact wire lengths/bends and finished solder joints require the actual parts. |

The revised USB collar is **9.6 × 3.6 mm**, with 0.2 mm clearance around the photo-derived **9.2 × 3.2 mm** metal shell. A 13.5 × 7.6 mm recess admits the USB-IF maximum cable overmold. The collar projects 0.30 mm beyond the modeled socket lip; a fully seated cable must leave at least 0.35 mm to clear it. This is a **required, unverified fit condition**, not a universally guaranteed USB dimension. The registered PCB cradle is needed to test the actual socket and cable before the case. See the [USB fit record](usb-fit.md).

## Measurements needed before declaring fit

The [key mounting guide](key-mounting.md) adds Gateron's specified plate and
aperture tolerances, lid reinforcement, clip retention and service procedure.
The hollow cap, socket and latch shapes in Blender explain the interfaces;
their unspecified dimensions remain approximations. The ribs are original
enclosure geometry, not a modification to the purchased switch.

1. **PCB:** overall size and thickness; both hole diameters; hole centre spacing; hole centre setback from the antenna edge. Measure from the edge to a hole's near edge and add half its diameter to obtain the centre setback.
2. **Populated board:** USB socket width, height and overhang; maximum top/bottom component height; button protrusions; solder-joint clearance. Keep all 32 electrical holes accessible.
3. **Keycap and switch:** cap stem seating depth, skirt clearance at full travel, overall heights and the switch's lowest pin after soldering. Target at least 2 mm from switch pins/solder to the tallest board component.
4. **Fasteners:** both nut sizes across flats/corners and thickness; both screw head diameters/heights and under-head lengths. Fit the two fastener coupons before the shell.
5. **Cable:** plug overmold width/height and enough insertion depth to seat fully through the rear wall.

Use those measurements to update the corresponding model inputs, regenerate in Blender, rerun the interference checks, and dry-fit a print. Manufacturer nominal dimensions and mesh checks alone cannot establish the final fit of a third-party board and custom keycap.

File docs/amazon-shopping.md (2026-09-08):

# Consolidated shopping plan

Listings checked September 5, 2026. Prices exclude shipping and tax and can change.
No purchases have been made by the project.

The fewest-orders route found is **one Amazon checkout plus one Max Keyboard
order**, assuming solder, filament, a suitable driver and a USB data cable are
already available. The revised design reuses the kit nuts but requires **M1.6 × 6
and M2 × 20 screws**; check the kit for those lengths before assuming coverage.
The revised Blender/STL files have exposed nuts and bottom-entry screw recesses. Measure the actual kit and fit the coupons before printing
the finished case. Separate Amazon sellers may
still ship in separate packages.

## Remaining purchases

| Buy once | Exact selection | Covers | Listed price |
| --- | --- | --- | --- |
| [Gateron Baby Kangaroo 2.0 switches — Amazon](https://www.amazon.com/dp/B0CM347W2W) | **10Pcs**, **Baby Kangaroo 2.0**, 5-pin mechanical MX style | One switch; nine spares. Same switch family selected for the model. Ships from Amazon, sold by kutethy at inspection. | **$7.99** |
| [METFUIN adhesive rubber sheets — Amazon](https://www.amazon.com/dp/B0FJ8WV32F?th=1) | Black, **1/25 Thick 6X6 inch**, two sheets | Cut four **8 × 8 mm** pads with rounded corners. Nominal thickness **1.016 mm**, close to the modeled 1 mm feet. Ships from Amazon. | **$6.99** |
| [Fermerry wire and insulation bundle — Amazon](https://www.amazon.com/dp/B089CXFH4H?th=1), **only if missing** | **30 AWG-6C**, **25FT** per color | Six colors of flexible tinned-copper silicone wire, **18 pieces of 2.4 mm heat-shrink tubing**, and 18 ties. Only two short wires and two joint sleeves are needed. Ships from Amazon, sold by Fermerry Technology. | **$10.29** |
| [Max Keyboard custom Tab keycap](https://maxkeyboard.com/custom-art-icon-or-text-cherry-mx-keycaps.html) | **R3 1x1.5 (Tab / \|)**, White, TOP Print only, `blocked` | One custom **1.5u Tab** cap, MX stem. Use the [existing artwork and settings](../keycap/README.md). Separate merchant order. | **$11.00** |

Amazon subtotal: **$14.98**, or **$25.27** with the wire bundle.
Including the custom cap: **$25.98**, or **$36.27** with the wire bundle,
before shipping/tax and any other missing supplies.

The rubber listing's selected variant is 1/25 inch; its generic dimensions table
disagrees. Check the delivered thickness before cutting. Its adhesive fixes the
feet to the case; the exposed rubber grips the desk by friction.

The wire listing specifies **0.8 mm insulation OD**, within the current 0.9 mm
wire envelope. The included tubing's shrink ratio is unpublished: check that it
stays over each soldered switch terminal without sliding and clears nearby
components. Do not count loose tubing as secure joint insulation.

No exact Amazon listing was verified for the required white, custom-printed
**1.5u Tab** cap. Personalized square caps and blank 1.5u caps do not meet that
requirement. A switch sampler also does not reliably include the selected switch;
the small matching pack is the useful purchase here.

## Reuse the ordered assortment

| Already ordered | Use per button | Compatibility status |
| --- | --- | --- |
| [Maierke 1050-piece M1.4/M1.6/M2/M2.5 socket-cap screw, nut and washer kit](https://www.amazon.com/dp/B0GKFMJH24?th=1) | **2 × M1.6 × 6 screws + 2 × M1.6 nuts** for the PCB; **2 × M2 × 20 screws + 2 × M2 nuts** for the case | Threads/nuts match the kit; inclusion of the revised 6 mm and 20 mm lengths is unverified. Nut thickness, screw-head size and the new print fit still need checking. |
| [Weideer 2322-piece M3 kit](https://www.amazon.com/dp/B0DS8HYF64?th=1) | No parts required for this enclosure | M3 is too large for the board's two dedicated mounting holes. Keep for other projects. |

Check the existing kit before buying any missing new-length screws. The switch clips
into its printed plate and the cap presses onto the MX stem; neither needs extra
screws or a stabilizer.

## Revised mounting

The current enclosure has four screws entering from the bottom and nuts openly
seated above the PCB/lid. The PCB uses its two dedicated holes plus two plain
USB-end supports. Feet have moved clear of every screw entry. Hold the exposed
nuts with fine pliers; remove the keycap for easier case-nut access.

Print the updated [M1.6 board coupon](../enclosure/stl/board-fastener-coupon.stl)
and [M2 case coupon](../enclosure/stl/case-fastener-coupon.stl) to check head-bore
clearance and full engagement with the new screw lengths. No nut trap needs fitting.
See [assembly instructions](enclosure.md) and the [fastener audit](fastener-fit.md).

Check existing soldering supplies, filament, USB data cable and matching hex
driver before placing the Amazon order. These are excluded from the totals above.
Standard M1.6 and M2 socket-cap screws both take a **1.5 mm hex key**
([supplier sizing table](https://www.modelfixings.co.uk/tools.htm)); check the
delivered kit matches. If that size is missing from existing tools, the
[Wera 05073593001 nine-piece metric set on Amazon](https://www.amazon.com/dp/B009ODV0OE)
includes it. US price was not verified; add it to the same checkout only if needed.

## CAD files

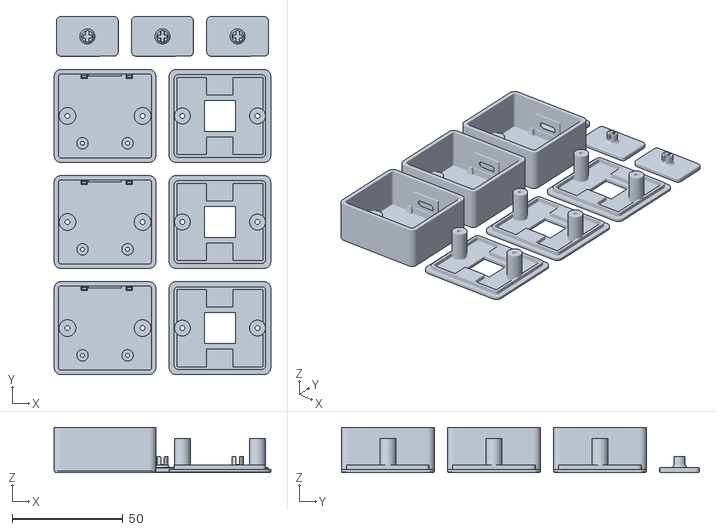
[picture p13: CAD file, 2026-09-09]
enclosure/stl/blocked-three-devices-blank-caps.stl
98.0 x 162.0 x 20.5

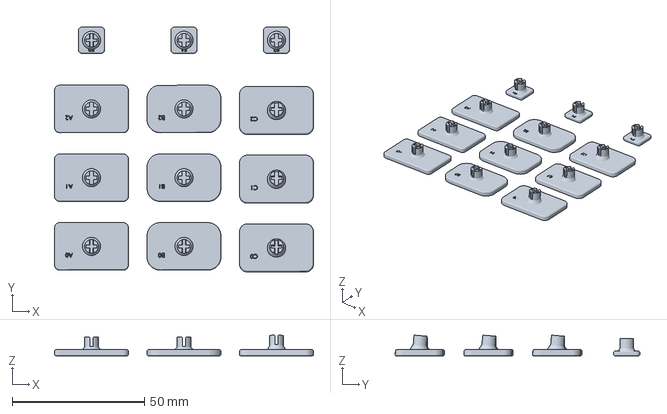
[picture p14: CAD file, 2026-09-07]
keycap/printed/blocked-tab-all-options.3mf
98.0 x 92.7 x 7.89 mm

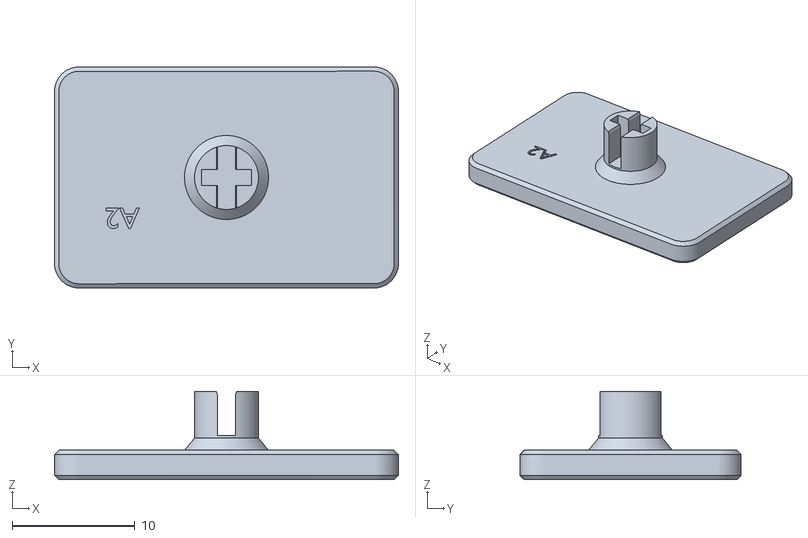
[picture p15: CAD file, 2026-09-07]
keycap/printed/stl/A2-flat-tab.stl
28.0 x 18.0 x 7.20

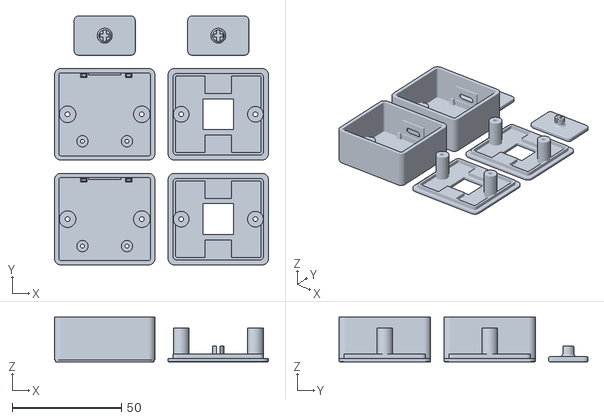
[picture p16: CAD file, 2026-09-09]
enclosure/stl/blocked-two-devices-blank-caps.stl
98.0 x 114.0 x 20.5

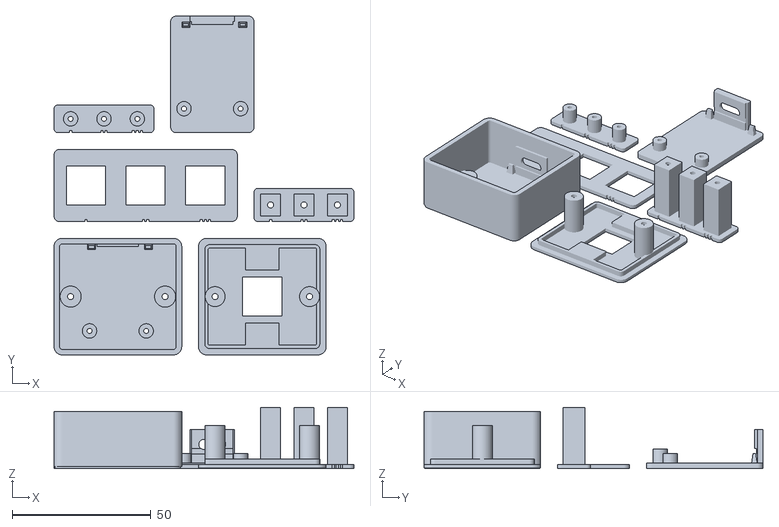
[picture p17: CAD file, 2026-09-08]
enclosure/stl/blocked-print-plate-with-coupons.stl
108.0 x 122.0 x 22.0

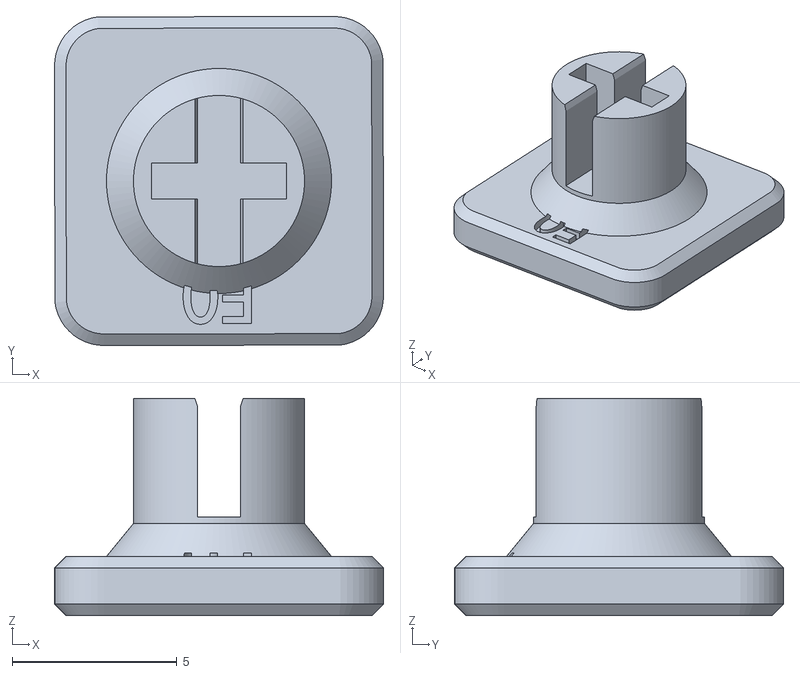
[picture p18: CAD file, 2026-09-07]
keycap/printed/stl/F0-socket-coupon.stl
10.0 x 10.0 x 6.60

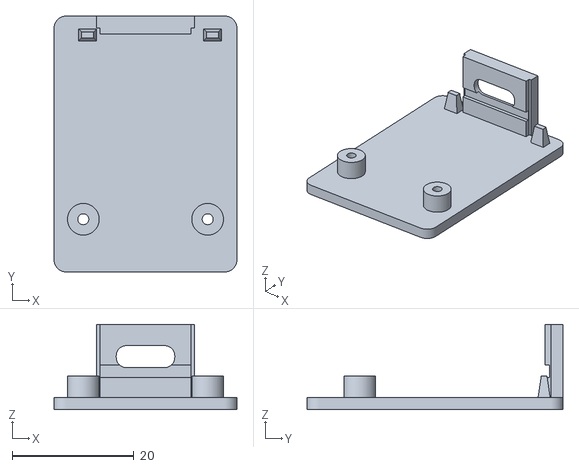
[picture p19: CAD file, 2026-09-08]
enclosure/stl/usb-fit-coupon.stl
30.0 x 42.0 x 14.0

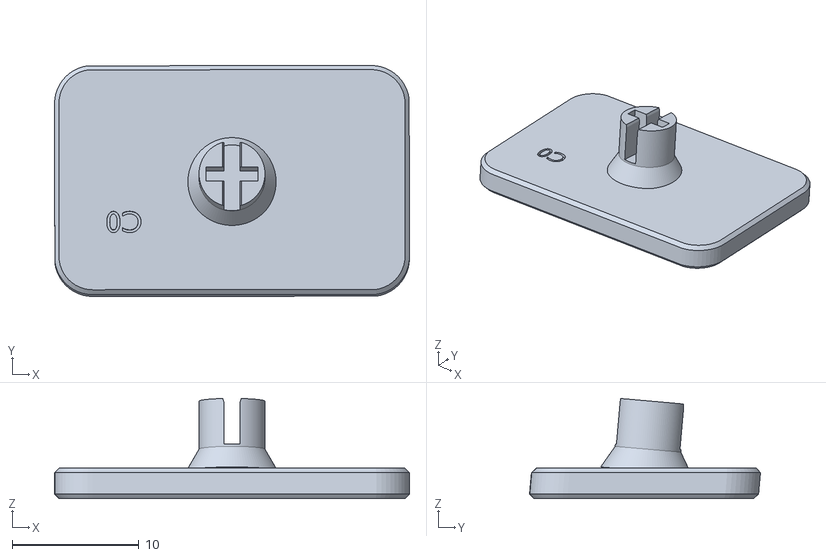
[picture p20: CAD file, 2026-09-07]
keycap/printed/stl/C0-tilt-tab.stl
28.0 x 18.2 x 7.89

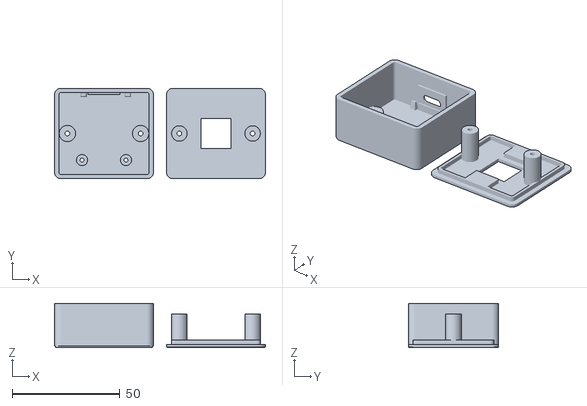
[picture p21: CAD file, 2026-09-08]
enclosure/stl/blocked-print-plate.stl
98.0 x 42.0 x 20.5

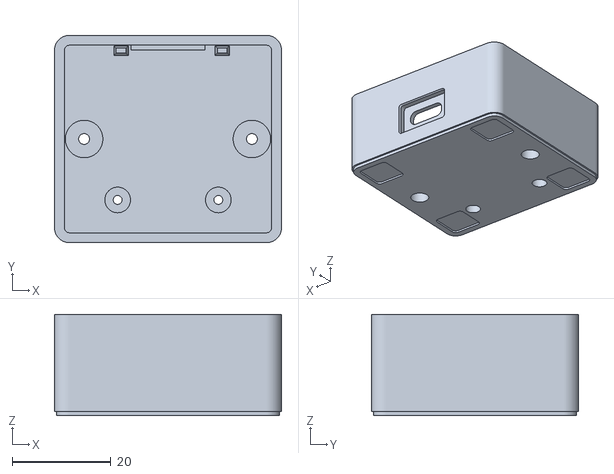
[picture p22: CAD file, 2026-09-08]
enclosure/stl/base.stl
46.0 x 42.0 x 20.5

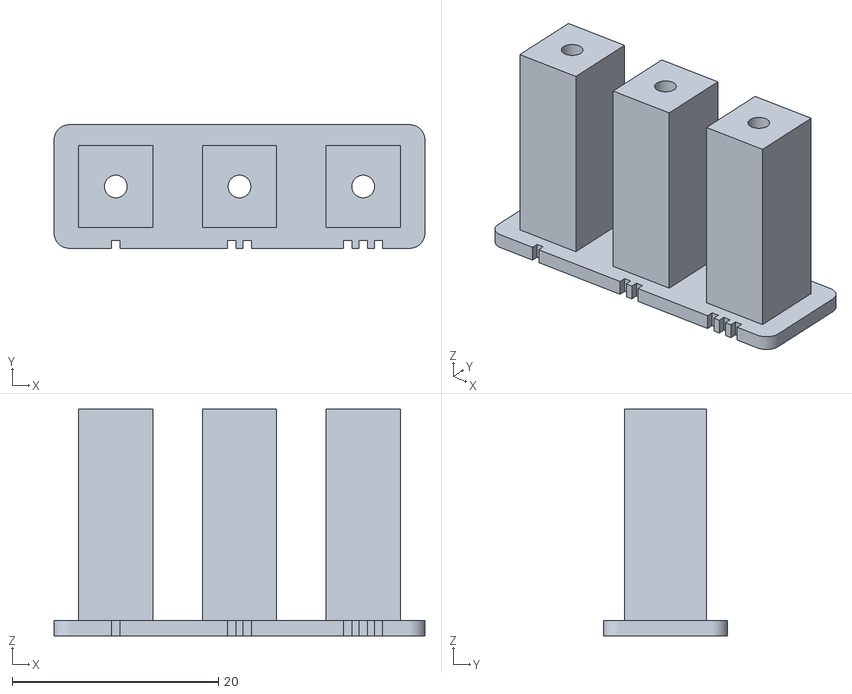
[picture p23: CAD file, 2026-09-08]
enclosure/stl/case-fastener-coupon.stl
36.0 x 12.0 x 22.0

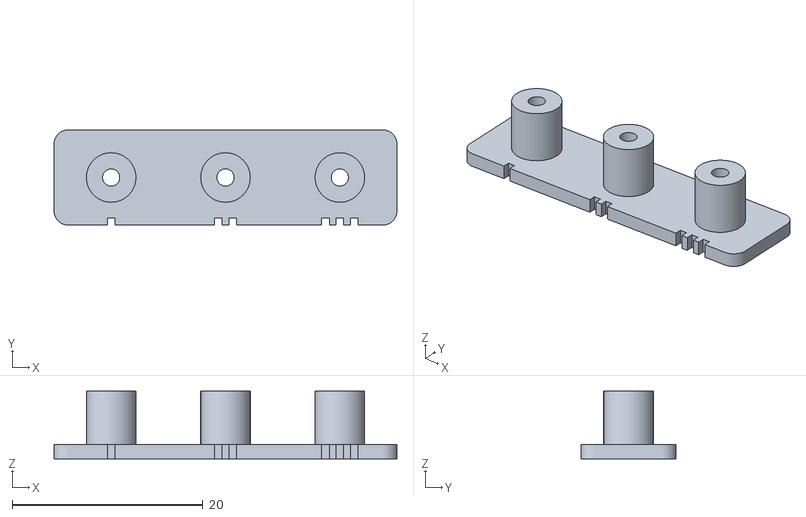
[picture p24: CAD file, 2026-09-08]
enclosure/stl/board-fastener-coupon.stl
36.0 x 10.0 x 7.10

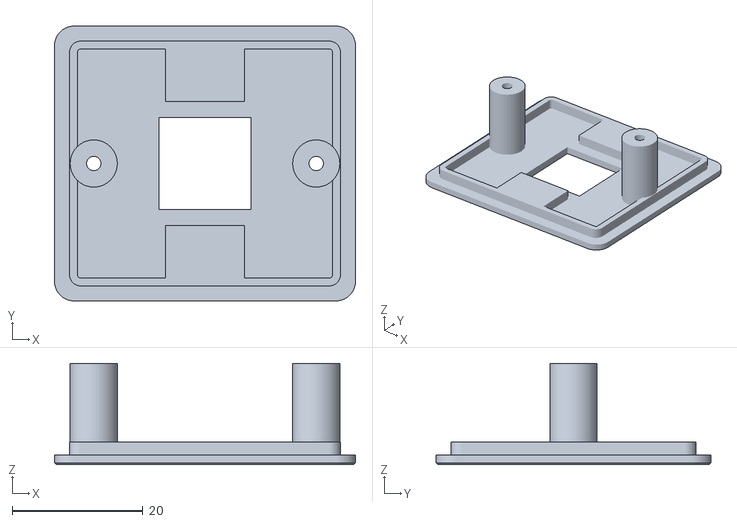
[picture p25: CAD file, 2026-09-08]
enclosure/stl/lid.stl
46.0 x 42.0 x 15.5

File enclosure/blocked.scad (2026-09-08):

// Generated by build.py from parameters.json. Units: mm.
// Change parameters.json and rerun build.py to edit dimensions.
part = "assembly"; // [assembly,base,lid,fit-coupon,case-fastener-coupon,board-fastener-coupon,usb-fit-coupon,print-layout]
module base() {
  difference() {
    union() {
      difference() {
        union() {
          translate([0, 0, 0]) linear_extrude(height=0.85, scale=1) offset(r=2.6, $fn=64) square([40, 36], center=true);
          translate([0, 0, 0.8]) linear_extrude(height=19.7, scale=1) offset(r=3, $fn=64) square([40, 36], center=true);
        }
        translate([0, 0, 2]) linear_extrude(height=20.5, scale=1) offset(r=1, $fn=64) square([40, 36], center=true);
      }
      translate([-10.2, -12.35, 1.95]) cylinder(h=3.55, r1=2.6, r2=2.6, $fn=64);
      translate([10.2, -12.35, 1.95]) cylinder(h=3.55, r1=2.6, r2=2.6, $fn=64);
      translate([-9.5, 17.9, 1.95]) linear_extrude(height=3.35,scale=[0.666667,0.5]) square([3,2],center=true);
      translate([-9.5, 17.9, 5.25]) translate([-1, -0.5, 0]) cube([2, 1, 0.25]);
      translate([11, 17.9, 1.95]) linear_extrude(height=3.35,scale=[0.666667,0.5]) square([3,2],center=true);
      translate([11, 17.9, 5.25]) translate([-1, -0.5, 0]) cube([2, 1, 0.25]);
      translate([0, 18.65, 2]) translate([-7.5, -0.6, 0]) cube([15, 1.2, 12]);
      translate([-17, 0, 1.95]) cylinder(h=4.25, r1=3.8, r2=3.8, $fn=64);
      translate([17, 0, 1.95]) cylinder(h=4.25, r1=3.8, r2=3.8, $fn=64);
    }
    translate([0, 20, 6.9]) translate([0,-3,1.8]) rotate([-90,0,0]) linear_extrude(height=6,scale=[1,1]) offset(r=1.65,$fn=64) square([6.3,0.3],center=true);
    translate([0, 21.125, 4.9]) translate([0,-1.875,3.8]) rotate([-90,0,0]) linear_extrude(height=3.75,scale=[1,1]) offset(r=0.7,$fn=64) square([12.1,6.2],center=true);
    translate([0, 20.825, 4.9]) translate([0,-0.225,3.8]) rotate([-90,0,0]) linear_extrude(height=0.45,scale=[1.04167,1.07401]) offset(r=0.7,$fn=64) square([12.1,6.2],center=true);
    translate([0, 17.875, 5.3]) translate([-7.55, -0.875, 0]) cube([15.1, 1.75, 2]);
    translate([-10.2, -12.35, -0.05]) cylinder(h=5.6, r1=0.9, r2=0.9, $fn=64);
    translate([-10.2, -12.35, -0.05]) cylinder(h=2.85, r1=1.8, r2=1.8, $fn=64);
    translate([10.2, -12.35, -0.05]) cylinder(h=5.6, r1=0.9, r2=0.9, $fn=64);
    translate([10.2, -12.35, -0.05]) cylinder(h=2.85, r1=1.8, r2=1.8, $fn=64);
    translate([-17, 0, -0.05]) cylinder(h=6.3, r1=1.1, r2=1.1, $fn=64);
    translate([-17, 0, -0.05]) cylinder(h=4.45, r1=2.2, r2=2.2, $fn=64);
    translate([17, 0, -0.05]) cylinder(h=6.3, r1=1.1, r2=1.1, $fn=64);
    translate([17, 0, -0.05]) cylinder(h=4.45, r1=2.2, r2=2.2, $fn=64);
    translate([-17, -15, -0.05]) linear_extrude(height=0.55, scale=1) offset(r=1, $fn=64) square([6, 6], center=true);
    translate([-17, 15, -0.05]) linear_extrude(height=0.55, scale=1) offset(r=1, $fn=64) square([6, 6], center=true);
    translate([17, -15, -0.05]) linear_extrude(height=0.55, scale=1) offset(r=1, $fn=64) square([6, 6], center=true);
    translate([17, 15, -0.05]) linear_extrude(height=0.55, scale=1) offset(r=1, $fn=64) square([6, 6], center=true);
  }
}
module lid() {
  difference() {
    union() {
      union() {
        translate([0, 0, 0]) linear_extrude(height=1.25, scale=1) offset(r=3, $fn=64) square([40, 36], center=true);
        translate([0, 0, 1.2]) linear_extrude(height=0.3, scale=0.986957) offset(r=3, $fn=64) square([40, 36], center=true);
      }
      difference() {
        translate([0, 0, -2]) linear_extrude(height=2.05, scale=1) offset(r=1.7, $fn=64) square([38, 34], center=true);
        translate([0, 0, -2.05]) linear_extrude(height=2.15, scale=1) offset(r=0.5, $fn=64) square([38, 34], center=true);
      }
      translate([-17, 0, -14]) cylinder(h=14.05, r1=3.6, r2=3.6, $fn=64);
      translate([17, 0, -14]) cylinder(h=14.05, r1=3.6, r2=3.6, $fn=64);
      translate([0, -14.05, -2]) translate([-6, -4.55, 0]) cube([12, 9.1, 2.05]);
      translate([0, 14.05, -2]) translate([-6, -4.55, 0]) cube([12, 9.1, 2.05]);
    }
    translate([0, 0, -0.05]) translate([-7.05, -7.05, 0]) cube([14.1, 14.1, 1.6]);
    translate([-17, 0, -14.05]) cylinder(h=15.6, r1=1.1, r2=1.1, $fn=64);
    translate([17, 0, -14.05]) cylinder(h=15.6, r1=1.1, r2=1.1, $fn=64);
  }
}
module fit_coupon() {
  difference() {
    translate([0, 0, 0]) linear_extrude(height=1.5, scale=1) offset(r=2, $fn=64) square([62, 22], center=true);
    translate([-21.5, 0, -0.05]) translate([-7, -7, 0]) cube([14, 14, 1.6]);
    translate([-21.5, -13, -0.05]) translate([-0.4, -0.75, 0]) cube([0.8, 1.5, 1.6]);
    translate([0, 0, -0.05]) translate([-7.05, -7.05, 0]) cube([14.1, 14.1, 1.6]);
    translate([-0.75, -13, -0.05]) translate([-0.4, -0.75, 0]) cube([0.8, 1.5, 1.6]);
    translate([0.75, -13, -0.05]) translate([-0.4, -0.75, 0]) cube([0.8, 1.5, 1.6]);
    translate([21.5, 0, -0.05]) translate([-7.1, -7.1, 0]) cube([14.2, 14.2, 1.6]);
    translate([20, -13, -0.05]) translate([-0.4, -0.75, 0]) cube([0.8, 1.5, 1.6]);
    translate([21.5, -13, -0.05]) translate([-0.4, -0.75, 0]) cube([0.8, 1.5, 1.6]);
    translate([23, -13, -0.05]) translate([-0.4, -0.75, 0]) cube([0.8, 1.5, 1.6]);
  }
}
module case_fastener_coupon() {
  difference() {
    union() {
      translate([0, 0, 0]) linear_extrude(height=1.5, scale=1) offset(r=1.5, $fn=64) square([33, 9], center=true);
      translate([-12, 0, 1.4]) translate([-3.6, -4, 0]) cube([7.2, 8, 20.6]);
      translate([0, 0, 1.4]) translate([-3.6, -4, 0]) cube([7.2, 8, 20.6]);
      translate([12, 0, 1.4]) translate([-3.6, -4, 0]) cube([7.2, 8, 20.6]);
    }
    translate([-12, 0, -0.05]) cylinder(h=22.1, r1=1.1, r2=1.1, $fn=64);
    translate([-12, 0, -0.05]) cylinder(h=4.45, r1=2.1, r2=2.1, $fn=64);
    translate([-12, -6, -0.05]) translate([-0.4, -0.75, 0]) cube([0.8, 1.5, 23]);
    translate([0, 0, -0.05]) cylinder(h=22.1, r1=1.1, r2=1.1, $fn=64);
    translate([0, 0, -0.05]) cylinder(h=4.45, r1=2.2, r2=2.2, $fn=64);
    translate([-0.75, -6, -0.05]) translate([-0.4, -0.75, 0]) cube([0.8, 1.5, 23]);
    translate([0.75, -6, -0.05]) translate([-0.4, -0.75, 0]) cube([0.8, 1.5, 23]);
    translate([12, 0, -0.05]) cylinder(h=22.1, r1=1.1, r2=1.1, $fn=64);
    translate([12, 0, -0.05]) cylinder(h=4.45, r1=2.3, r2=2.3, $fn=64);
    translate([10.5, -6, -0.05]) translate([-0.4, -0.75, 0]) cube([0.8, 1.5, 23]);
    translate([12, -6, -0.05]) translate([-0.4, -0.75, 0]) cube([0.8, 1.5, 23]);
    translate([13.5, -6, -0.05]) translate([-0.4, -0.75, 0]) cube([0.8, 1.5, 23]);
  }
}
module board_fastener_coupon() {
  difference() {
    union() {
      translate([0, 0, 0]) linear_extrude(height=1.5, scale=1) offset(r=1.5, $fn=64) square([33, 7], center=true);
      translate([-12, 0, 1.4]) cylinder(h=5.7, r1=2.6, r2=2.6, $fn=64);
      translate([0, 0, 1.4]) cylinder(h=5.7, r1=2.6, r2=2.6, $fn=64);
      translate([12, 0, 1.4]) cylinder(h=5.7, r1=2.6, r2=2.6, $fn=64);
    }
    translate([-12, 0, -0.05]) cylinder(h=7.2, r1=0.9, r2=0.9, $fn=64);
    translate([-12, 0, -0.05]) cylinder(h=2.85, r1=1.7, r2=1.7, $fn=64);
    translate([-12, -5, -0.05]) translate([-0.4, -0.75, 0]) cube([0.8, 1.5, 8.1]);
    translate([0, 0, -0.05]) cylinder(h=7.2, r1=0.9, r2=0.9, $fn=64);
    translate([0, 0, -0.05]) cylinder(h=2.85, r1=1.8, r2=1.8, $fn=64);
    translate([-0.75, -5, -0.05]) translate([-0.4, -0.75, 0]) cube([0.8, 1.5, 8.1]);
    translate([0.75, -5, -0.05]) translate([-0.4, -0.75, 0]) cube([0.8, 1.5, 8.1]);
    translate([12, 0, -0.05]) cylinder(h=7.2, r1=0.9, r2=0.9, $fn=64);
    translate([12, 0, -0.05]) cylinder(h=2.85, r1=1.9, r2=1.9, $fn=64);
    translate([10.5, -5, -0.05]) translate([-0.4, -0.75, 0]) cube([0.8, 1.5, 8.1]);
    translate([12, -5, -0.05]) translate([-0.4, -0.75, 0]) cube([0.8, 1.5, 8.1]);
    translate([13.5, -5, -0.05]) translate([-0.4, -0.75, 0]) cube([0.8, 1.5, 8.1]);
  }
}
module usb_fit_coupon() {
  difference() {
    union() {
      translate([0, 0, 0]) linear_extrude(height=2, scale=1) offset(r=2, $fn=64) square([26, 38], center=true);
      translate([-10.2, -12.35, 1.95]) cylinder(h=3.55, r1=2.6, r2=2.6, $fn=64);
      translate([10.2, -12.35, 1.95]) cylinder(h=3.55, r1=2.6, r2=2.6, $fn=64);
      translate([-9.5, 17.9, 1.95]) linear_extrude(height=3.35,scale=[0.666667,0.5]) square([3,2],center=true);
      translate([-9.5, 17.9, 5.25]) translate([-1, -0.5, 0]) cube([2, 1, 0.25]);
      translate([11, 17.9, 1.95]) linear_extrude(height=3.35,scale=[0.666667,0.5]) square([3,2],center=true);
      translate([11, 17.9, 5.25]) translate([-1, -0.5, 0]) cube([2, 1, 0.25]);
      translate([0, 18.65, 2]) translate([-7.5, -0.6, 0]) cube([15, 1.2, 12]);
      translate([0, 20, 1.95]) translate([-8, -1, 0]) cube([16, 2, 12.05]);
    }
    translate([0, 20, 6.9]) translate([0,-3,1.8]) rotate([-90,0,0]) linear_extrude(height=6,scale=[1,1]) offset(r=1.65,$fn=64) square([6.3,0.3],center=true);
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

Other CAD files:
keycap/printed/stl/A0-flat-tab.stl
keycap/printed/stl/C2-tilt-tab.stl
keycap/printed/stl/F1-socket-coupon.stl
keycap/printed/stl/B0-soft-tab.stl
keycap/printed/stl/B2-soft-tab.stl
enclosure/blocked.blend
enclosure/stl/fit-coupon.stl
enclosure/usb-review.blend
keycap/printed/blocked-tab-options.blend
keycap/printed/stl/A1-flat-tab.stl
keycap/printed/stl/B1-soft-tab.stl
keycap/printed/stl/C1-tilt-tab.stl
keycap/printed/stl/F2-socket-coupon.stl
keycap/printed/stl/blocked-tab-all-options.stl
keycap/printed/stl/socket-fit-coupons.stl

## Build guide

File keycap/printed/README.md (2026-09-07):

# Print a `blocked` Tab keycap

Three slim **28 × 18 mm, 1.5u-style Tab prototypes** for the selected Gateron Baby
Kangaroo 2.0 switch. They push onto its cross stem; no keycap screw, glue or
stabilizer is needed. The switch itself still clips into the enclosure's lid.
These are purpose-designed printable caps, separate from the illustrative
purchased-keycap model in `enclosure/`.

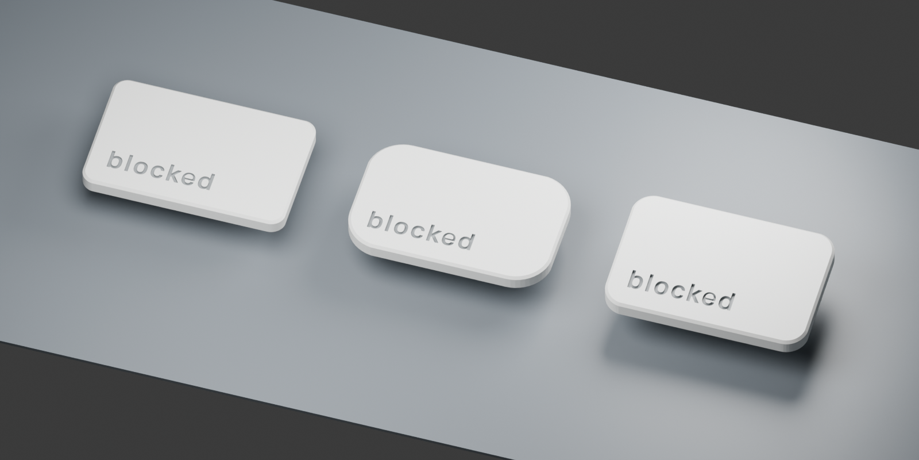
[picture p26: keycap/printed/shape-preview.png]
Flat, soft and tilted Tab prototypes


The render shows optional gray paint in the engraving. A single white filament
prints the whole cap, including the recessed lettering; an AMS is not needed.

## Files to print

- **[Bambu Studio A1 project](blocked-tab-all-options.3mf)**: open as a project
  to retain the arranged parts and supplied process settings. Select your
  actual PLA spool and plate, then **Slice plate** and inspect the preview.
- **[All options, one STL](stl/blocked-tab-all-options.stl)**: nine caps and three
  socket testers, already laid out face-down on a **98 × 92.68 mm** footprint.
- **[Socket testers only](stl/socket-fit-coupons.stl)**: the quickest first print.
- Individual caps and testers are in [stl/](stl/).
- **[Editable Blender source](blocked-tab-options.blend)** includes the arranged
  print plate and hidden copies in installed orientation.

Import in **millimeters, 100% scale**. Preserve the supplied orientation. The
caps' upper faces are against the bed and their sockets point upward. Do not
auto-orient them. The combined STL has 12 deliberately separate shells; keep
their relative positions if the slicer asks about importing multiple objects.
This plate contains keycaps and socket testers only, not the enclosure parts.

| Shape | Underside IDs | Shape choice |
| --- | --- | --- |
| A — Flat Tab | A0, A1, A2 | Closest to the restrained Apple-style outline; 2 mm corner radius |
| B — Soft Tab | B0, B1, B2 | Softer 5 mm corners, same flat pressing face |
| C — Tilt Tab | C0, C1, C2 | Face slopes up 5° toward the back; 3 mm corners |

All have a 2.4 mm crown and 0.35 mm edge chamfers. C is rotated by 175° for
printing so its sloped face lies flat on the bed. A/B and the testers are
rotated 180°. The lack of a surrounding skirt leaves more room around the
switch housing. These are individual button shapes, not replicas of an OEM
keyboard row profile.

In the STL's XY layout, columns left-to-right are A, B, C. Rows from lower to
higher Y are fits 0, 1, 2. Three smaller F0/F1/F2 testers occupy the last row.
Each piece also has a recessed ID underneath.

## Bambu Lab A1 settings

Designed around the **stock 0.4 mm nozzle and regular PLA**. The printer model
is confirmed; nozzle and material are assumptions. Use the material preset
that matches the actual spool. Avoid silk PLA for this small spring-fit socket.

| Setting | Use |
| --- | --- |
| Printer | Bambu Lab A1, 0.4 mm nozzle |
| Process baseline | 0.12 mm High Quality |
| Layer height / first layer | 0.12 mm / 0.20 mm |
| Wall generator | Arachne |
| Walls / infill | 4 walls / 100% infill |
| Supports / raft / brim | Off / off / none |
| Outer walls / first layer | 30 mm/s / 20 mm/s |
| Elephant-foot compensation | 0 mm for this face-down plate; the crown has an edge chamfer |
| Ironing | Off — the visible face is on the bed |
| Scale and orientation | 100%, as supplied |

Use a clean plate and run the appropriate flow calibration for the filament.
A smooth plate gives the most keyboard-like upper face; the A1's textured PEI
plate works but transfers its texture to the cap and small lettering. Set the
actual plate type in Bambu Studio and retain the matching filament/plate
temperature preset. This design doesn't require a new plate.

The engraving is **0.4 mm deep**, with a 14.1 mm-wide lowercase word expanded
outward by 0.07 mm. Added letter spacing and a 0.15 mm enlargement of the tiny
`e` counter preserve details that the first A1 slice lost. This is a
print-adapted version of the SF Compact artwork,
not the finer 9 mm-wide vendor upload. Preview the first few layers: the holes
inside letters must remain present. Do not put supports into the socket or
enable a global XY-size adjustment to tune it: that also changes the exterior.

A **0.2 mm A1 nozzle is an optional improvement** for lettering and thin socket
walls. If using one, select its real printer/nozzle profile, use 0.08–0.12 mm
layers, and repeat the socket test. A smaller layer height on the 0.4 mm nozzle
alone does not give it a 0.2 mm nozzle's XY detail. Do not reuse a sliced 0.4 mm
project unchanged with different hardware.

The [A1 process preset](a1-process.json) and [slicer verification report](slicer-validation.json)
record the checked settings and results. The 3MF is an editable, unsliced
project. The standard STL also works in other slicers with the settings above.

Bambu Studio 2.8.2.61 estimates **1 h 22 min 40 s and 14.32 g of PLA** for the
whole plate with the supplied settings (65 layers). Its final toolpaths retain
all seven separate engraved letters and all four letter centers on all nine
caps in both first layers. The inspected socket paths stay open, and no model
warnings were reported. These are slicer checks and estimates, not a completed
physical print; the report lists the inspection limits and profile metadata
warnings.

## Choose the fit before assembly

The numeric suffix controls the **total extra width**, not clearance per side:

| Fit | Horizontal pocket thickness | Through-slot width | Starting order |
| --- | --- | --- | --- |
| 0 | 1.10 mm | 1.30 mm | Tightest |
| 1 | 1.20 mm | 1.40 mm | Middle |
| 2 | 1.30 mm | 1.50 mm | Try first, roomiest |

The horizontal pocket's span is 4.10 mm. The perpendicular slot opens through
both ends of a **5.2 mm diameter boss**, creating two compliant halves joined
above the 3.6 mm-deep recess. The root widens above 3.8 mm. Wall thickness near
the pocket corners is roughly 0.47–0.49 mm: inspect these features rather than
assuming a manifold STL guarantees a strong print.

1. Let the print cool and inspect the socket. Remove loose strings only; do not
   drill, glue or force it onto the stem.
2. With USB disconnected, support the switch body and try **F2** gently by hand,
   then F1 and F0 if needed. Keep the X/Y orientation: the two cross-bar widths
   differ. Do not rotate a cap 90° to make it fit.
3. Choose the fit that seats securely and can be removed with a straight pull
   without excessive force. A tester that bottoms on the guard instead of
   seating on the cross does not pass. If none fits, measure the printed socket
   and switch and adjust the geometry; don't scale the whole cap.
4. Fit the corresponding A/B/C cap. F testers use the flat print orientation;
   the tilted C socket must also be checked because it prints at 5° to Z.
5. Press fully at the center and each corner, then release repeatedly. Confirm
   the full stroke, free spring return, no rubbing, no cracks and no unseating.
   Stop if it sticks or the root touches the surrounding guard/housing.

**Physical fit has not been verified.** Gateron documents the cross and travel,
but does not dimension the surrounding guard's inside clearance, the cap's
female socket or its seating depth. The 5.2 mm boss, 3.6 mm engagement and axial
seat are testable prototype choices. The testers deliberately expose those
uncertainties before relying on a finished cap.

With the existing assembly's *assumed* male cross top 8.4 mm above the plate,
seating at the recess ceiling puts the socket mouth at 4.8 mm. At full 3.4 mm
travel it is 1.4 mm above the plate. The crown remains at least about 0.94 mm
above the modeled 5 mm housing top; the root flare starts 0.2 mm above it.
The narrow boss still enters the housing's undimensioned central opening.
These nominal clearances do not establish the actual installed height or fit.

## Why these shapes and print choices

There is no universally perfect printed keycap. A finger dish can feel nice,
but it introduces a curved overhang when printed face-down. Printing it with
the socket down instead compromises the small fit surfaces or needs supports.
For a first A1 batch, broad planar faces let all three shapes use the same
support-free approach while comparing corner feel and face angle. Try the
physical prints to choose the most comfortable one.

- [Gateron's Baby Kangaroo 2.0 drawing, last page](https://gateron.com/u_file/2308/29/file/GATERONBabyKangaroo20Switch-b4b5.pdf)
  specifies 4.00 +0.05/−0.10 mm cross spans, 1.10 ±0.04 / 1.30 ±0.04 mm bar
  thicknesses and 3.4 mm maximum travel. Those asymmetric dimensions informed
  the socket; unmarked dimensions were not treated as exact.
- [KeyV2's stem implementation](https://github.com/rsheldiii/KeyV2/blob/master/src/stems/cherry.scad)
  demonstrates opening one arm through the socket for compliance. Its
  [dimensions](https://github.com/rsheldiii/KeyV2/blob/master/src/functions.scad)
  and [printing notes](https://github.com/rsheldiii/KeyV2/blob/master/TIPS_AND_TRICKS.md)
  show why stem fit and first-layer effects need tuning. We use that concept
  with original Blender geometry and Gateron-oriented dimensions; no KeyV2
  source code or mesh is bundled.
- [Prusa's design guidance](https://help.prusa3d.com/article/modeling-with-3d-printing-in-mind_164135)
  explains orientation, tolerances and wall/extrusion width. Its
  [nozzle comparison](https://blog.prusa3d.com/everything-about-nozzles-with-a-different-diameter_8344/)
  distinguishes XY detail from layer height.
- [Craig Andrews' documented keycap experiments](https://candrews.integralblue.com/2024/03/3d-printing-high-quality-keycaps/)
  are useful practical evidence for fine nozzles, tilted sculpted-cap printing
  and avoiding weak silk-PLA sockets. They are not measurements of this switch.
- [Bambu's A1 quick-start guide](https://cdn1.bambulab.com/documentation/quick-start-a75adcb1d5d5e/Quick%20Start%20Guide%20for%20A1.pdf)
  documents the supplied 0.4 mm nozzle. Slicing uses the official
  [Bambu Studio](https://github.com/bambulab/BambuStudio) A1 profiles.

## Reproduce and inspect

Run from the repository root using Blender 5.2.1 (tested):

```sh
/Applications/Blender.app/Contents/MacOS/Blender \
  --background --factory-startup --threads 4 \
  --python keycap/printed/build.py
```

The generator exports every cap, both combined plates, the Blender file,
preview and [mesh report](validation.json). Each printable part must be one
closed, manifold, positive-volume solid. It stops exporting on a failed check.
The STL units are mm; the Blender scene uses a 0.001 m unit scale.

Run the separate exported-file check with
`python3 keycap/printed/check-exported.py`. Its [independent report](independent-audit.json)
checks binary STL topology, volume, bed contact, part spacing and component
matching, and recovers the nominal crown/root travel clearances from the
exported geometry. It does not measure the real switch or certify socket fit.

The widened glyph contours are checked in, so Blender needs no extra Python
packages. Only when changing the artwork, regenerate them with:

```sh
uv run --with shapely==2.1.2 python keycap/printed/prepare-legend.py
```

All dimensions are in `build.py` and `validation.json`. The original
[vendor upload artwork](../README.md) is unchanged. No font binary is included.

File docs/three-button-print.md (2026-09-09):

# Print three complete buttons

Download [the single nine-part STL](../enclosure/stl/blocked-three-devices-blank-caps.stl).
It contains **three bases, three lids, and three blank 1.5u-style Tab keycaps** using the
latest socket-hugging USB collar. There are no engraved words or underside IDs
on any cap. No fit coupons or electronics are included in this plate.

The caps use **A2 Flat Tab**: 28 × 18 mm, rounded 2 mm corners, and the roomiest of the
existing three split MX socket fits. This is the recommended first trial from
[the keycap guide](../keycap/printed/README.md); actual switch fit remains unverified.

## Bambu Lab A1

- Import in **millimeters at 100% scale**. The nine parts occupy 98 × 162 mm, centered
  on the 256 × 256 mm bed, with at least 6 mm between parts.
- **Preserve their supplied positions and orientation.** Bases are floor-down;
  lids are top-down; keycaps are face-down with their sockets pointing upward.
  If Bambu Studio asks about multiple objects, keep all nine shells and their
  relative arrangement. Do not auto-orient them.
- Starting settings assume the stock **0.4 mm nozzle and regular PLA**: 0.12 mm
  layers, 0.20 mm first layer, Arachne walls, 4 walls, 100% infill, supports off.
  Use the correct filament and plate preset for your actual spool and bed.
- Slice and inspect the socket walls, open cross recesses, USB bridges and bottom
  screw recesses. A smooth plate gives the blank cap faces a smoother finish;
  textured PEI transfers its texture. No AMS is required.

Let the caps cool fully before trying them. Support the switch body and press
straight down gently; do not force, rotate or glue a tight cap. The existing
[F2 socket tester](../keycap/printed/stl/F2-socket-coupon.stl) can be printed first
if you have not yet established a fit. The narrow split socket walls remain a
physical print-strength and fit check.

The current snug USB collar is still a **prototype requiring a physical fit test**. Its dimensions
assume the board model and require sufficient clearance behind your fully seated
cable shoulder. Test the real board and cable in the
[registered USB cradle](../enclosure/stl/usb-fit-coupon.stl) before committing to
all three complete bases; see [USB fit details](usb-fit.md).

The [validation report](../enclosure/three-device-plate-validation.json) records
nine manifold, connected, positive-volume parts after reimporting the exported
STL; z0 contact, part separation, source hashes and open-socket probes also pass.
These are geometry checks, not a completed slice or physical print.

Rebuild without modifying any existing Blender scene:

```sh
/Applications/Blender.app/Contents/MacOS/Blender \
  --background --factory-startup --threads 4 \
  --python enclosure/two-device-plate.py -- --sets 3
```

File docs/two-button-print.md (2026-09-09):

# Print two complete buttons

Download [the single six-part STL](../enclosure/stl/blocked-two-devices-blank-caps.stl).
It contains **two bases, two lids, and two blank 1.5u-style Tab keycaps** using the
latest socket-hugging USB collar. There are no engraved words or underside IDs
on either cap. No fit coupons or electronics are included in this plate.

The caps use **A2 Flat Tab**: 28 × 18 mm, rounded 2 mm corners, and the roomiest of the
existing three split MX socket fits. This is the recommended first trial from
[the keycap guide](../keycap/printed/README.md); actual switch fit remains unverified.

## Bambu Lab A1

- Import in **millimeters at 100% scale**. The six parts occupy 98 × 114 mm, centered
  on the 256 × 256 mm bed, with at least 6 mm between parts.
- **Preserve their supplied positions and orientation.** Bases are floor-down;
  lids are top-down; keycaps are face-down with their sockets pointing upward.
  If Bambu Studio asks about multiple objects, keep all six shells and their
  relative arrangement. Do not auto-orient them.
- Starting settings assume the stock **0.4 mm nozzle and regular PLA**: 0.12 mm
  layers, 0.20 mm first layer, Arachne walls, 4 walls, 100% infill, supports off.
  Use the correct filament and plate preset for your actual spool and bed.
- Slice and inspect the socket walls, open cross recesses, USB bridges and bottom
  screw recesses. A smooth plate gives the blank cap faces a smoother finish;
  textured PEI transfers its texture. No AMS is required.

Let the caps cool fully before trying them. Support the switch body and press
straight down gently; do not force, rotate or glue a tight cap. The existing
[F2 socket tester](../keycap/printed/stl/F2-socket-coupon.stl) can be printed first
if you have not yet established a fit. The narrow split socket walls remain a
physical print-strength and fit check.

The current snug USB collar is still a **prototype requiring a physical fit test**. Its dimensions
assume the board model and require sufficient clearance behind your fully seated
cable shoulder. Test the real board and cable in the
[registered USB cradle](../enclosure/stl/usb-fit-coupon.stl) before committing to
both complete bases; see [USB fit details](usb-fit.md).

The [validation report](../enclosure/two-device-plate-validation.json) records
six manifold, connected, positive-volume parts after reimporting the exported
STL; z0 contact, part separation, source hashes and open-socket probes also pass.
These are geometry checks, not a completed slice or physical print.

Rebuild without modifying any existing Blender scene:

```sh
/Applications/Blender.app/Contents/MacOS/Blender \
  --background --factory-startup --threads 4 \
  --python enclosure/two-device-plate.py
```

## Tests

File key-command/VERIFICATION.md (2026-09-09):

# Key Command verification

Local checks on September 8, 2026:

- `swift test`: **14 tests passed, 0 failures**. Tests exercise protocol identity and UInt32 rollover, persisted per-device bindings, busy/disabled/diagnostic action gating, multiple USB ports and duplicate IDs, same-path replacement, sleep/partial-frame/burst suppression, shortcut permission/focus/held-key guards, and actual zsh execution.
- Command tests execute harmless fixtures with an isolated shell startup directory. They verify exact script handling, a working-directory path containing shell syntax, pipes/redirection, stderr and exit codes, noninteractive stdin, bounded output, timeout, pre-launch cancellation, and process-group cancellation including a TERM-ignoring descendant.
- Firmware compiled using pinned Arduino ESP32 3.3.1 for LOLIN S2 Mini: **302,342 bytes flash, 34,752 bytes global RAM**. Portable parser/button-state tests passed with address/undefined-behavior sanitizers. No board was flashed.
- Release package builds both **arm64 and x86_64**. Packaging verifies app signatures, the DMG checksum, the mounted app executable against its source, and the Applications shortcut.
- Installed and opened `/Applications/Key Command.app`. Native UI review checked both action views, command pasting/selection, and shortcut capture. Temporary drafts were cleared; no action was enabled, Accessibility approval was not granted, and no shortcut was sent to another app.
- The two-device STL was reimported into Blender: six manifold connected parts, positive volume, all on z0, minimum 6 mm spacing, 98 × 114 mm footprint. Blank-cap sockets remain open; no top or underside lettering is included.

The beta is ad-hoc signed and **not Apple-notarized**. Physical USB detection, unplug/replug with the additional boards, and actual keyboard-shortcut delivery require the new hardware and the user's macOS Accessibility approval. Unit tests verify shortcut policy but do not claim an event was accepted by a real target app. The snug USB collar and cap sockets retain their documented physical-fit requirements.

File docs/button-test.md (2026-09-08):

# Test the soldered button over USB

**Blocked Button Tester** is a standalone Mac window showing live
**PRESSED / RELEASED**, hold duration, a press counter and recent events.
It has no GitHub CLI, Chrome automation or review action and works offline.

## First setup

1. Unplug USB while soldering. Connect board pad **4 / IO4** to either metal
   switch terminal, and **GND** to the other. Insulate joints and inspect for
   bridges. No external resistor is needed.
2. Upload the latest [firmware](../firmware/README.md#flash) once. This version
   includes the `TEST` command; older firmware needs updating. Hold **0 / BOOT**,
   tap **RESET**, release BOOT after USB reconnects, then upload. Tap RESET after
   uploading. Keep the lid open during setup.
3. Quit the normal **Blocked** menu-bar app and other serial monitors.
4. Open `companion/dist/Blocked Button Tester.app` and connect a **USB data cable**.
   It automatically finds firmware identifying itself as `Blocked Key`, including
   a board that was connected before the tester opened.

After that initial firmware upload, just plug in USB for ordinary testing;
no BOOT/RESET sequence is needed each time. The same firmware works with the
regular companion afterward: quit the tester and reopen Blocked.

## Expected behavior

| Action | Expected result |
| --- | --- |
| Plug in, switch released | Connected, RELEASED, no extra press |
| Push the switch | PRESSED, counter increases once |
| Keep holding | Hold timer runs; counter stays unchanged |
| Release | RELEASED |
| Press ten separate times | Counter increases by ten |
| Plug in with the switch held | PRESSED / HELD ON CONNECT, no counted press until release and a fresh press |
| Unplug | Live state clears; tester waits for reconnection |
| Reset counter while held | Zero until the next new press |

The display reports electrical input, not mechanical travel or joint strength.
The initial state is an immediate pin snapshot; subsequent changes are
debounced for 25 ms. Shorter presses may not register. The counter records
observed transitions while connected and does not recover offline presses.
The board sends a state heartbeat every second; the app clears a stale
connection after three seconds without valid responses.

**Stuck PRESSED:** release the switch, then check for an IO4-to-GND short,
bridged solder or a jammed switch. **Always RELEASED:** check for an open joint,
the wrong board pad or soldering to something other than the two metal switch
terminals. With USB unplugged, continuity should appear only when pressed.

**Waiting for USB:** check for a data cable and uploaded firmware. An Espressif
board found under another USB product name is shown as needing setup; the
tester does not send commands to arbitrary serial devices. **Firmware needs an
update:** the `Blocked Key` device did not answer `TEST`; upload current firmware.
**Port busy:** close the other serial app and click Reconnect.

## Build and verify

From the repository root:

```sh
bash companion/scripts/build-tester.sh
open "companion/dist/Blocked Button Tester.app"
```

This builds a universal Intel/Apple Silicon app for macOS 13+, signs it locally
and verifies its signature. It requires no GitHub credentials. It is a local
build, not a notarized distribution release.

Run `swift test` from `companion/` for protocol and companion tests. The new
protocol tests cover identity, held snapshots, one count per edge, heartbeat
repeats, malformed input and reconnects. [Firmware tests](../firmware/README.md)
cover debounce, diagnostic heartbeat and mode changes. Firmware compilation
uses the pinned ESP32 3.3.1 core. The real USB bench test still needs your board,
cable and soldered switch.

The tester sends `TEST`, accepts `BLOCKED_TEST 1`, then reads `STATE UP/DOWN`.
Firmware emits no production `PRESS` messages in diagnostic mode. The tester
obtains exclusive serial access and waits for you to quit the ordinary Blocked
app before opening the device. Its `ButtonTestCore` parser target has no
dependency on the review application.

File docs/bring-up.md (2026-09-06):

# Build it in stages

This project starts as an unassembled prototype. Build the electrical and
software loop on the desk before sealing anything in a printed case.

## 1. Check the board

Confirm it is an **ESP32-S2 Mini**, with native USB, and compare its shape and
pin labels with [the hardware guide](hardware.md). The enclosure is based on a
headerless LOLIN S2 Mini; measure clones before printing. Use a USB **data** cable.
An LED lighting up only proves the cable supplies power.

## 2. Check the switch and solder two wires

Print the switch coupon and lid first, following the [key mounting guide](key-mounting.md).
Check both retaining clips and cap travel on the coupon, then clip the switch
into the final lid before connecting both ends of its wires. The flange and
ESP32 are too large to thread through the switch aperture afterward.

With everything unplugged, use a multimeter's continuity mode across the two
metal switch contacts: open when released, connected when pressed. Wire one
contact to the documented button GPIO and the other to GND. The switch has no
polarity. Do not connect a switch contact to 5 V.

Tin the wire and contact first, solder briefly, insulate exposed switch contacts,
and leave a small service loop so the lid can lift off. Check for bridges before
plugging in. See [hardware](hardware.md) for the selected GPIO and pin cautions.

## 3. Flash and test dry-run

Follow [firmware setup](../firmware/README.md), then close any serial monitor so
the companion can own the USB port. Build and open
[Blocked.app](../companion/README.md). Connect the recipient's own GitHub account in the setup window and grant Chrome Automation permission during the companion setup.

Keep Blocked paused. Choose **Test next press (no review)**, focus a GitHub
pull request in Google Chrome and press the physical key. Confirm that the preview contains the expected PR,
action, and the exact body `blocked`.

## 4. Try the important edge cases

These are manual acceptance checks, **not a claim that they have passed on
physical hardware**. For each diagnostic press, keep Blocked paused and choose
**Test next press (no review)** again. Later presses remain paused:

| Check | Expected result |
| --- | --- |
| Plug in with the key released | Connects; no review event |
| Plug in while holding the key | No event until released and pressed again |
| Hold the key for several seconds | One event |
| Tap repeatedly | Debounce/cooldown suppress duplicates |
| Focus a different app while Chrome remains open | No review |
| Focus a normal GitHub page or an issue | No review |
| Open two Chrome windows with different PRs | Targets the front window's active tab |
| Switch to Files changed / Commits / Checks | Still identifies the same PR |
| Disconnect and reconnect USB | Reconnects without a stale press |
| Quit and reopen Blocked | Keeps enabled/paused intent; paused stays paused |
| Deny Automation or remove CLI authentication | Clear failure; no fallback target |
| Disconnect network during a live test | No automatic retry; inspect GitHub manually |

Only after dry-run works, enable live reviews and test once on a PR whose owner
has agreed to the test. The recipient must use their own GitHub CLI identity.
Do not use their own authored PR to test request-changes; GitHub restricts
self-reviews. Confirm the posted review reads exactly `blocked`.

## 5. Finish the case and check the assembly

Use [the enclosure guide](enclosure.md). With the switch coupon and lid already
checked, print the fastener coupons and remaining shell. Check the actual board, plug
overmold, screws, wire routing, and key travel. Nothing should flex the PCB or
press against a solder joint. Adjust the parameters if your printer or clone
board needs different clearances.

## 6. Finish the gift

Order the white **1.5u Tab-width keycap** using the [exact settings and artwork](../keycap/README.md),
with a small lowercase **blocked** legend at the front-left. The
revised render pairs it with a satin silver housing and a dark inset bottom
seam. Silver/gray filament gives the color; sanding, primer, and metallic paint
are optional finishing steps if you want to approach the render's finish.
Recess the adhesive pads so they barely protrude. Put the USB-C cable, the repo
URL, and the Mac setup instructions in the box.

The first build requires soldering, flashing, and local app setup. Once those
are done, everyday use is: open Blocked, enable live reviews, focus a PR, press.

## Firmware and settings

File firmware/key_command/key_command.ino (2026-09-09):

#include <Arduino.h>
#include <USB.h>
#include <USBCDC.h>
#include <esp_mac.h>
#include <atomic>
#include "ButtonSession.h"
#include "CommandParser.h"

#if !CONFIG_IDF_TARGET_ESP32S2
#error "Select LOLIN S2 Mini; this firmware targets ESP32-S2."
#endif
#if ARDUINO_USB_CDC_ON_BOOT
#error "Disable USB CDC On Boot: this sketch creates its own CDC interface."
#endif

constexpr uint8_t kButtonPin = 4;
USBCDC keySerial;
ButtonSession button;
CommandParser parser;
char deviceID[13];
std::atomic<uint32_t> disconnectEpoch{0};
uint32_t observedEpoch = 0;
uint32_t sequence = 0;

bool isPressed() { return digitalRead(kButtonPin) == LOW; }

void onCDCEvent(void *, esp_event_base_t, int32_t event, void *) {
  if (event == ARDUINO_USB_CDC_DISCONNECTED_EVENT) {
    disconnectEpoch.fetch_add(1, std::memory_order_relaxed);
  }
}

void resetSession() {
  parser.reset();
  button.disconnect(isPressed(), millis());
}

void sendOutput(ButtonSession::Output output) {
  switch (output) {
    case ButtonSession::Output::Press:
      keySerial.printf("PRESS %lu\n", static_cast<unsigned long>(++sequence));
      break;
    case ButtonSession::Output::StateUp: keySerial.print("STATE UP\n"); break;
    case ButtonSession::Output::StateDown: keySerial.print("STATE DOWN\n"); break;
    case ButtonSession::Output::None: break;
  }
}

void handleCommand(CommandParser::Command command) {
  if (command == CommandParser::Command::Hello) {
    button.hello(isPressed(), millis());
    keySerial.printf("KEY_COMMAND 1 %s\n", deviceID);
  } else if (command == CommandParser::Command::Test) {
    const auto snapshot = button.test(isPressed(), millis());
    keySerial.printf("KEY_COMMAND_TEST 1 %s\n", deviceID);
    sendOutput(snapshot);
  }
}

void setup() {
  pinMode(kButtonPin, INPUT_PULLUP);
  resetSession();
  // Factory eFuse base MAC: persistent per-chip identity, not a user credential.
  // Refuse to advertise a fabricated/shared identity if reading the eFuse fails.
  uint8_t mac[6];
  if (esp_efuse_mac_get_default(mac) != ESP_OK) {
    while (true) delay(1000);
  }
  snprintf(deviceID, sizeof(deviceID), "%02X%02X%02X%02X%02X%02X",
           unsigned(mac[0]), unsigned(mac[1]), unsigned(mac[2]),
           unsigned(mac[3]), unsigned(mac[4]), unsigned(mac[5]));
  USB.productName("Key Command");
  USB.serialNumber(deviceID);
  // Keep the LOLIN/Espressif board VID/PID. No custom vendor identity.
  keySerial.onEvent(onCDCEvent);
  keySerial.enableReboot(false);
  keySerial.setRxBufferSize(256);
  keySerial.setTxTimeoutMs(10);
  keySerial.begin(115200);
  USB.begin();
}

void loop() {
  const uint32_t epoch = disconnectEpoch.load(std::memory_order_relaxed);
  if (epoch != observedEpoch) {
    observedEpoch = epoch;
    resetSession();
  }
  if (!keySerial) {
    resetSession();
    // Fixed budget even if an unconfigured host continuously sends bytes.
    for (unsigned count = 0; count < 64 && keySerial.available(); ++count) keySerial.read();
    delay(1);
    return;
  }
  for (unsigned count = 0; count < 64 && keySerial.available(); ++count) {
    handleCommand(parser.feed(static_cast<char>(keySerial.read())));
  }
  sendOutput(button.update(isPressed(), millis()));
  delay(1);
}

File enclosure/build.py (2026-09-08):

#!/usr/bin/env python3
"""One geometry tree generates both OpenSCAD and Blender STL output.

python3 enclosure/build.py                       # regenerate .scad
blender -b --python enclosure/build.py -- --export # regenerate .scad + STL
No third-party Python packages are needed; STL export runs inside Blender 4+.
All coordinates and exported STL units are millimeters.
"""
from __future__ import annotations

import json
import math
from pathlib import Path
import sys

ROOT = Path(__file__).resolve().parent
P = json.loads((ROOT / "parameters.json").read_text())
C = json.loads((ROOT / "component-models.json").read_text())
EPS = 0.05


def shape(kind, **data):
    return {"kind": kind, **data}


def box(w, d, h, x=0, y=0, z=0):
    return shape("box", w=w, d=d, h=h, x=x, y=y, z=z)


def rounded(w, d, h, r, x=0, y=0, z=0, top_scale=1):
    return shape("rounded", w=w, d=d, h=h, r=r, x=x, y=y, z=z, top_scale=top_scale)


def tunnel(w,d,h,r,x=0,y=0,z=0,flare=0):
    """Rounded X/Z opening extruded along Y; optional outward (+Y) lead-in."""
    return shape('tunnel',w=w,d=d,h=h,r=r,x=x,y=y,z=z,flare=flare)


def cylinder(r, h, x=0, y=0, z=0, top=None):
    return shape("cylinder", r=r, top=r if top is None else top,
                 h=h, x=x, y=y, z=z)


def hexagon(af, h, x=0, y=0, z=0):
    return shape('hex', af=af, h=h, x=x, y=y, z=z)


def frustum(w,d,top_w,top_d,h,x=0,y=0,z=0):
    return shape('frustum',w=w,d=d,top_w=top_w,top_d=top_d,h=h,x=x,y=y,z=z)


def union(*children):
    return shape("union", children=list(children))


def difference(body, *cuts):
    return shape("difference", children=[body, *cuts])


def geometry():
    w, d, h = P["width"], P["depth"], P["base_height"]
    wall, floor, plate = P["wall"], P["floor"], P["plate"]
    r, sx, br = P["corner_radius"], P["screw_x"], P["boss_radius"]
    assert w > P["board_width"] + 2 * wall
    assert d > P["board_depth"] + 2 * wall
    assert sx - br > P["board_width"] / 2 + P["board_clearance"]
    assert sx + br <= w / 2 - wall - P["lid_clearance"] + EPS
    assert floor > P["pad_recess"] + 1
    assert 0 < P["switch_opening"] < 18
    assert P["usb_bottom"] >= floor
    assert P["usb_bottom"] + P["usb_height"] < h
    assert P['case_pad_top']-P['case_head_recess_depth'] >= 1.8-EPS
    assert P['board_bottom']-P['board_head_recess_depth'] >= 2.7-EPS
    band, inset = P['bottom_band_height'], P['bottom_inset']
    shell = difference(
        union(rounded(w - 2*inset, d - 2*inset, band + EPS, r-inset),
              rounded(w, d, h-band, r, z=band)),
        rounded(w - 2 * wall, d - 2 * wall, h, r - wall, z=floor),
    )
    additions = []
    # Two existing mounting holes clamp the PCB; two USB-end strips support it.
    for x in (-P['board_mount_x'], P['board_mount_x']):
        additions.append(cylinder(P['board_post_radius'],P['board_bottom']-floor+EPS,
                                  x=x,y=P['board_mount_y'],z=floor-EPS))
    for x in (P['front_support_left_x'],P['front_support_right_x']):
        collar_z=P['board_bottom']-P['front_support_contact_height']
        additions.extend([
            frustum(P['front_support_base_width'],P['front_support_base_depth'],
                    P['front_support_width'],P['front_support_depth'],collar_z-floor+EPS,
                    x=x,y=P['front_support_y'],z=floor-EPS),
            box(P['front_support_width'],P['front_support_depth'],P['front_support_contact_height']+EPS,
                x=x,y=P['front_support_y'],z=collar_z-EPS)])
    board_additions=list(additions)
    collar=box(P['usb_collar_width'],P['usb_face_y']-P['usb_collar_back'],
               P['usb_collar_top']-floor,y=(P['usb_face_y']+P['usb_collar_back'])/2,z=floor)
    additions.append(collar)
    for x in (-sx,sx):
        additions.append(cylinder(P['case_pad_radius'],P['case_pad_top']-floor+EPS,x=x,z=floor-EPS))
    usb_cuts=[
        tunnel(P['usb_width'],2*wall+2,P['usb_height'],P['usb_corner_radius'],
               y=d/2-wall/2,z=P['usb_bottom']),
        tunnel(P['usb_outer_width'],d/2+2-P['usb_face_y'],P['usb_outer_height'],P['usb_outer_radius'],
               y=(d/2+2+P['usb_face_y'])/2,z=P['usb_outer_bottom']),
        tunnel(P['usb_outer_width'],P['usb_leadin_depth']+EPS,P['usb_outer_height'],P['usb_outer_radius'],
               y=d/2-P['usb_leadin_depth']/2+EPS/2,z=P['usb_outer_bottom'],
               flare=P['usb_leadin_flare']*(P['usb_leadin_depth']+EPS)/P['usb_leadin_depth']),
        box(P['usb_pcb_relief_width'],P['usb_pcb_relief_front']-17,
            P['usb_pcb_relief_top']-P['usb_pcb_relief_bottom'],
            y=(17+P['usb_pcb_relief_front'])/2,z=P['usb_pcb_relief_bottom'])]
    cuts=list(usb_cuts)
    for x in (-P['board_mount_x'],P['board_mount_x']):
        cuts.extend([
            cylinder(P['board_screw_clearance']/2,P['board_bottom']+2*EPS,
                     x=x,y=P['board_mount_y'],z=-EPS),
            cylinder(P['board_head_recess_diameter']/2,P['board_head_recess_depth']+EPS,
                     x=x,y=P['board_mount_y'],z=-EPS)])
    for x in (-sx, sx):
        cuts.extend([
            cylinder(P['case_screw_clearance']/2,P['case_pad_top']+2*EPS,x=x,z=-EPS),
            cylinder(P['case_head_recess_diameter']/2,P['case_head_recess_depth']+EPS,x=x,z=-EPS)])
    for x in (-P['foot_x'],P['foot_x']):
        for y in (-P['foot_y'],P['foot_y']):
            cuts.append(rounded(P["pad_size"], P["pad_size"],
                                P["pad_recess"] + EPS, 1, x=x, y=y, z=-EPS))
    base = difference(union(shell, *additions), *cuts)
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

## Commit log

2026-09-06 feat: build the blocked PR review key prototype
    [base.stl, blocked.blend, blocked.scad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]
2026-09-06 docs: record firmware and prototype verification
2026-09-06 design: widen the key and refine the silver enclosure
    [base.stl, blocked.blend, blocked.scad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]
2026-09-06 docs: choose the custom blocked keycap and condense the BOM
2026-09-06 docs: link every BOM purchase and specify Tab keycap size
2026-09-06 feat: add mechanical PCB retention and threaded enclosure mounts
    [base.stl, blocked.blend, blocked.scad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]
2026-09-06 fix: mount S2 Mini through dedicated holes and verify component clearance
    [base.stl, blocked.blend, blocked.scad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]
2026-09-06 feat: reinforce and document the switch and Tab keycap mount
    [blocked.blend, blocked.scad, lid.stl]
2026-09-06 test: exercise Chrome capture and PR review submission flow
2026-09-06 docs: define reset and boot service access after assembly
2026-09-06 feat: revise enclosure for captive nuts and socket-cap screws
    [base.stl, blocked.blend, blocked.scad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]
2026-09-07 feat: add combined STL print plates
    [blocked-print-plate-with-coupons.stl, blocked-print-plate.stl]
2026-09-07 design: match keycap gray to sampled Apple reference imagery
2026-09-07 design: add printable Tab keycap options and verified A1 project
    [A0-flat-tab.stl, A1-flat-tab.stl, A2-flat-tab.stl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]
2026-09-08 feat: add USB button tester and diagnostic firmware mode
2026-09-08 feat: expose enclosure nuts and support all four PCB corners
    [base.stl, blocked-print-plate-with-coupons.stl, blocked-print-plate.stl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]
2026-09-08 feat: tighten USB opening and add fit coupon with Blender review views
    [base.stl, blocked-print-plate-with-coupons.stl, blocked-print-plate.stl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]
2026-09-08 feat: fit a recessed collar around the USB socket with test cradle
    [base.stl, blocked-print-plate-with-coupons.stl, blocked-print-plate.stl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]
2026-09-09 feat: add standalone Key Command app and two-button blank-cap print plate
    [blocked-two-devices-blank-caps.stl]
2026-09-09 feat: add three-button print plate with blank Tab caps
    [blocked-three-devices-blank-caps.stl]
